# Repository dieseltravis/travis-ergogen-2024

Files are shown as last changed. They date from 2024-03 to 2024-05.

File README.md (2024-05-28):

# Travis's Ergogen Keyboard 2024 #
Built with Ergogen v4. *Beta* quality!

keyboard plate outline

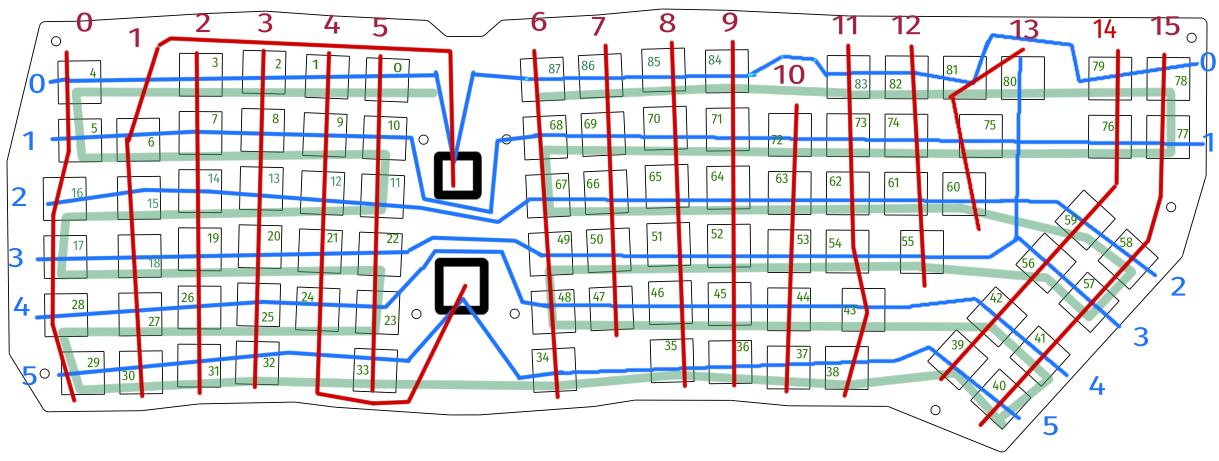
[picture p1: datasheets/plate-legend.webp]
rough keyboard key and led mapping


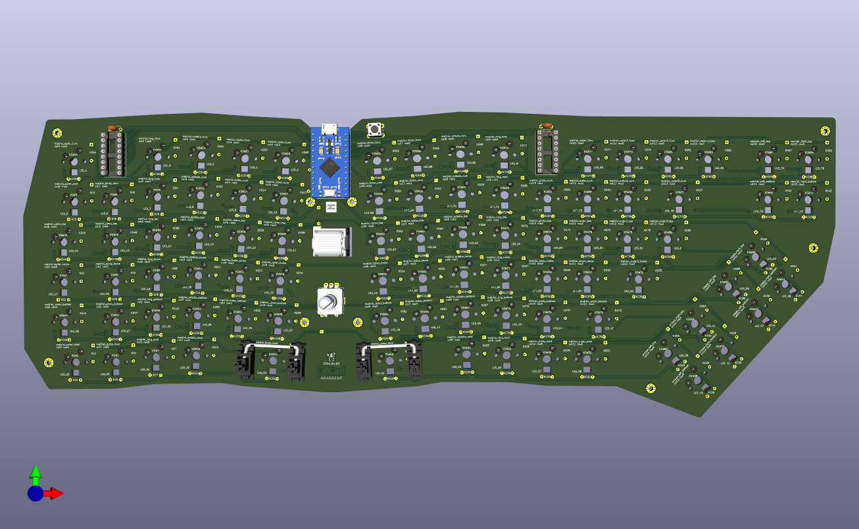
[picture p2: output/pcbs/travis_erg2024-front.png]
PCB front


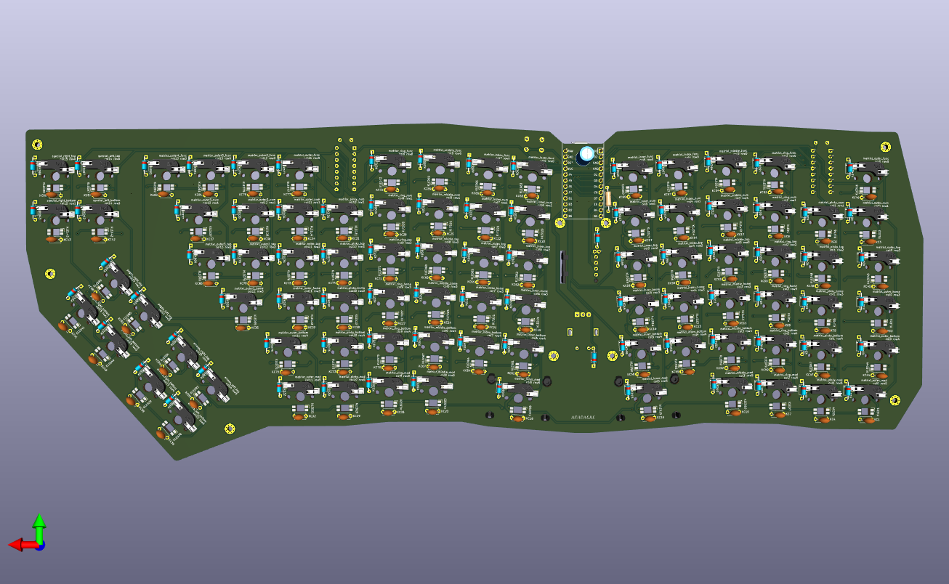
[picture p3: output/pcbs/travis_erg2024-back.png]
PCB back


keyboard-layout-editor.com

## Project Details ##
* `/config.yaml` Ergogen layout
* `/package.json` yarn commands and metadata
* `/output/outlines/` generated 2d models
* `/output/cases/` generated 3d models
* `/output/pcbs/` generated PCB
* `/footprints/travis/` Custom parts' footprints
    * `/footprints/travis/travis.pretty/` KiCad footprints
* `/key/` generator for individual key footprint (key-module.js)
    * `/keytest/` test for individual key footprint
* `/datasheets/` PDFs for some of the parts used
* `/kle/` keyboard-layout-editor.com layouts
* `/firmware/` qmk firmware compiles, but needs to be tested!

## References ##
* Ergogen project: https://github.com/ergogen/ergogen/
    * https://ergogen.cache.works/
    * https://ergogen.xyz/
* FlatFootFox's Let's Design A Keyboard With Ergogen v4 https://flatfootfox.com/ergogen-introduction/
* Footprints:
    * ceoloide's Ergogen PCB footprints https://github.com/ceoloide/ergogen-footprints
    * infused-kim's Ergogen PCB footprints https://github.com/infused-kim/kb_ergogen_fp/
    * TildeWill's Ergogen PCB footprints https://github.com/TildeWill/ergogen_footprints
    * MvEerd https://github.com/MvEerd/ergogen/tree/mveerd/src/footprints
    * daprice's keyswitches.pretty https://github.com/daprice/keyswitches.pretty
    * joe-scotto's scottokeebs: https://github.com/joe-scotto/scottokeebs/tree/main/Extras/ScottoKicad
    * Convert Kicad Footprints to Ergogen https://nilnil.notion.site/Convert-Kicad-Footprints-to-Ergogen-8340ce87ad554c69af4e3f92bc9a0898
    * KiCad Footprints: https://kicad.github.io/footprints/
* Other helpful build guides:
    * ceoloide's corney-island build https://github.com/ceoloide/corney-island
    * zzeneg's stront40 https://github.com/zzeneg/stront/tree/stront40
    * Minecatr's Splinar+ https://github.com/Minecatr/keyboards/
    * Kimiko Build Guide https://keycapsss.com/help/kimiko/buildguide_en
    * Nullbits Nibble https://github.com/nullbitsco/docs/blob/main/nibble/build_guide_en.md
    * Lagom https://github.com/mohoyt/lagom/
    * Sundown-keyboard https://github.com/Richiban/Sundown-keyboard/
    * Mantis hex ergo keyboard https://github.com/fxkuehl/mantis/
    * Sofle Keyboard https://github.com/josefadamcik/SofleKeyboard

## Parts ##

Aliexpress:
* Diodes: DO-35 1N4148 100pcs https://www.aliexpress.us/item/3256805608834808.html
* Rotary encoder: EC11 12.5mm 5pcs https://www.aliexpress.us/item/2251832789732148.html
* EVQWGD001 Encoder: https://www.aliexpress.us/item/3256806010310254.html
* IC SN74HC138N 10pcs https://www.aliexpress.us/item/3256806021872320.html
* RGB LEDs: SK6812 MINI-E 100pcs https://www.aliexpress.us/item/2255800289371100.html
* Capacitors: 104(0.1uF) 100pcs https://www.aliexpress.us/item/3256802104127109.html
* Resistor: 470R 100pcs https://www.aliexpress.us/item/3256801441680644.html
* Electrolytic Capacitor: 6.3V1000UF 6x11mm 10pcs https://www.aliexpress.us/item/3256802796040934.html

Adafruit:
* Adafruit KB2040 - RP2040 Kee Boar Driver https://www.adafruit.com/product/5302
* 5 @ Kailh Switch Sockets for MX-compatible Mechanical Keys - 20 Pack https://www.adafruit.com/product/4958
* 10 @ Kailh Mechanical Key Switches - Tactile Brown - 10 pack - Cherry MX Brown Compatible https://www.adafruit.com/product/4954
* 10 @ DSA Keycaps for MX Compatible Switches - 10 pack https://www.adafruit.com/product/5008
* USB A to USB C Cable - 2 meters long https://www.adafruit.com/product/5044

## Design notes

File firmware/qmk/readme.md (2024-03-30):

# dieseltravis/travis_ergogen_2024

dieseltravis/travis_ergogen_2024

*A short description of the keyboard/project*

* Keyboard Maintainer: [Travis Hardiman](https://github.com/dieseltravis)
* Hardware Supported: *The PCBs, controllers supported*
* Hardware Availability: *Links to where you can find this hardware*

Make example for this keyboard (after setting up your build environment):

    make dieseltravis/travis_ergogen_2024:default

Flashing example for this keyboard:

    make dieseltravis/travis_ergogen_2024:default:flash

See the [build environment setup](https://docs.qmk.fm/#/getting_started_build_tools) and the [make instructions](https://docs.qmk.fm/#/getting_started_make_guide) for more information. Brand new to QMK? Start with our [Complete Newbs Guide](https://docs.qmk.fm/#/newbs).

## Bootloader

Enter the bootloader in 3 ways:

* **Bootmagic reset**: Hold down the key at (0,0) in the matrix (usually the top left key or Escape) and plug in the keyboard
* **Physical reset button**: Briefly press the button on the back of the PCB - some may have pads you must short instead
* **Keycode in layout**: Press the key mapped to `RESET` if it is available

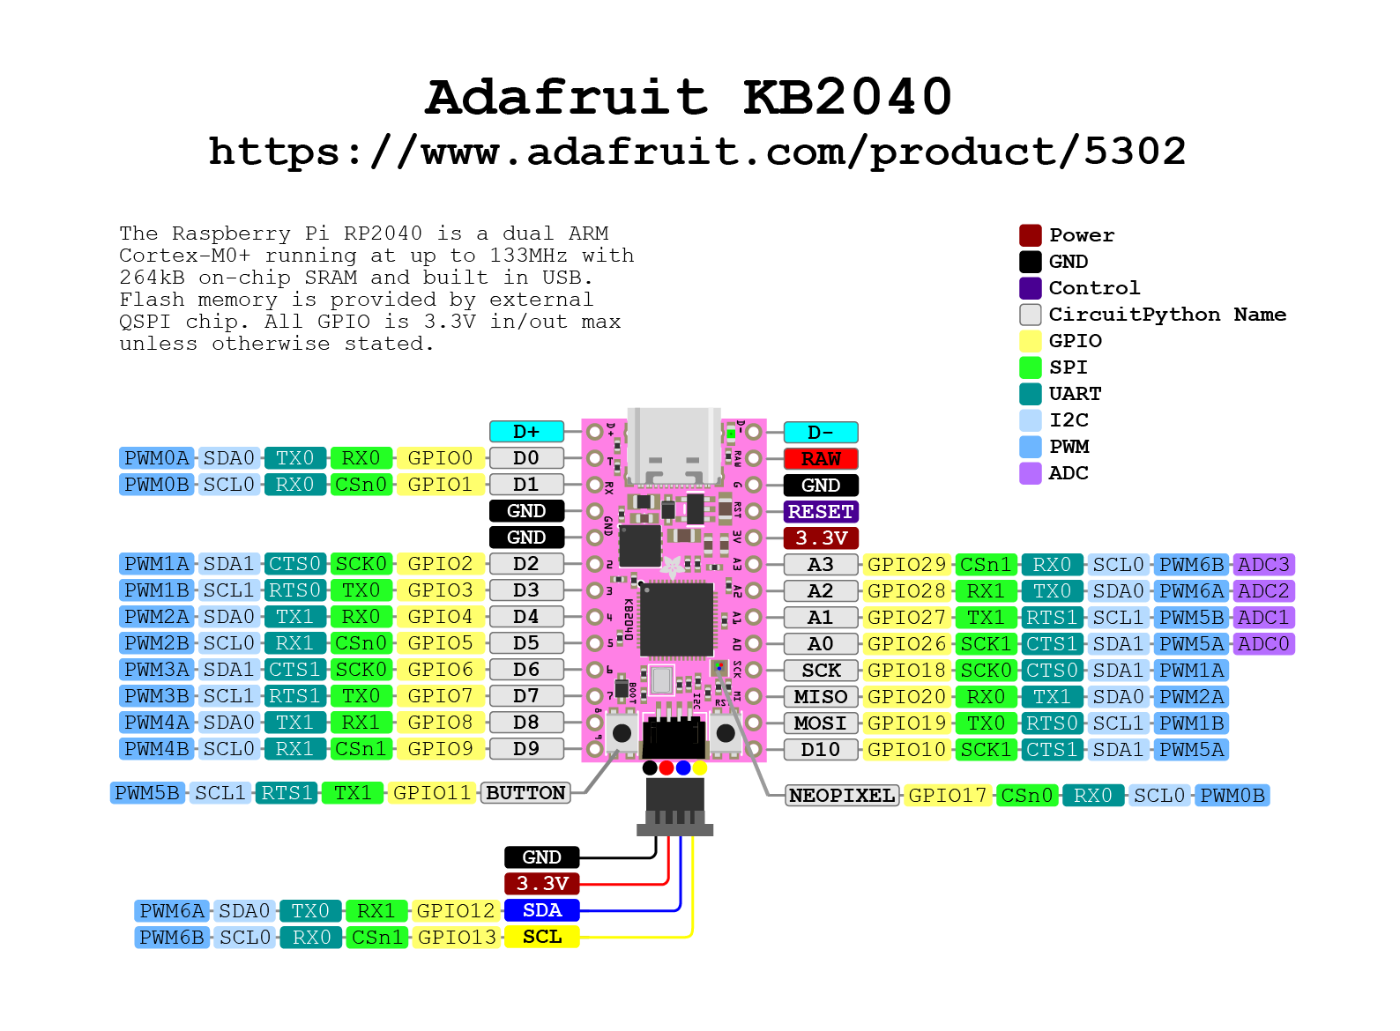
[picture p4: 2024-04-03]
datasheets/adafruit_products_Adafruit_KB2040_Pinout.png

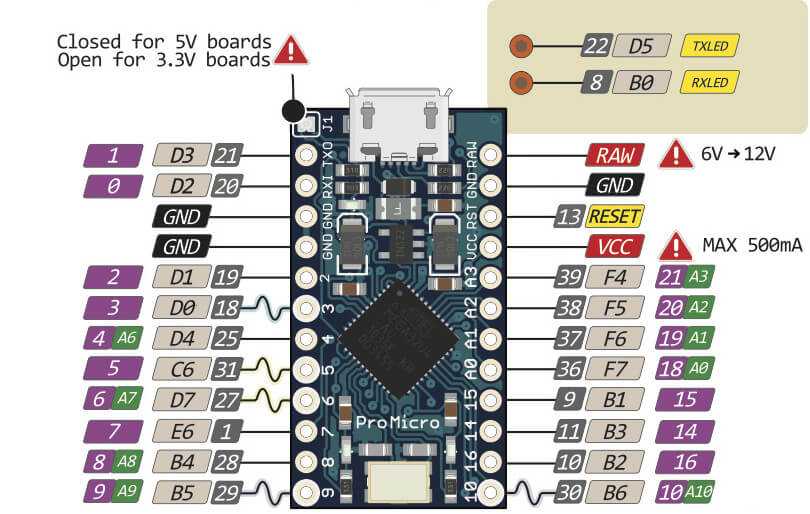
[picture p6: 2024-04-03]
datasheets/pro_micro_pinout.jpeg

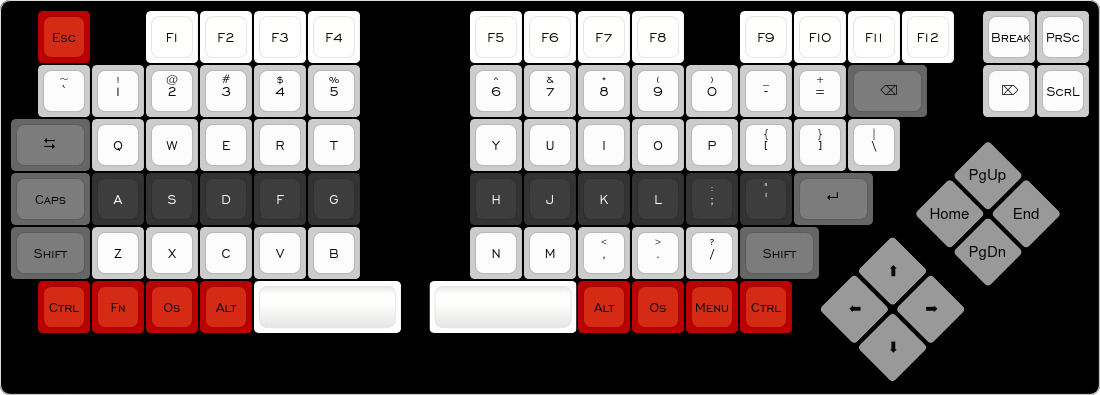
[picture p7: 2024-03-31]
kle/travis-ergogen-2024.jpg

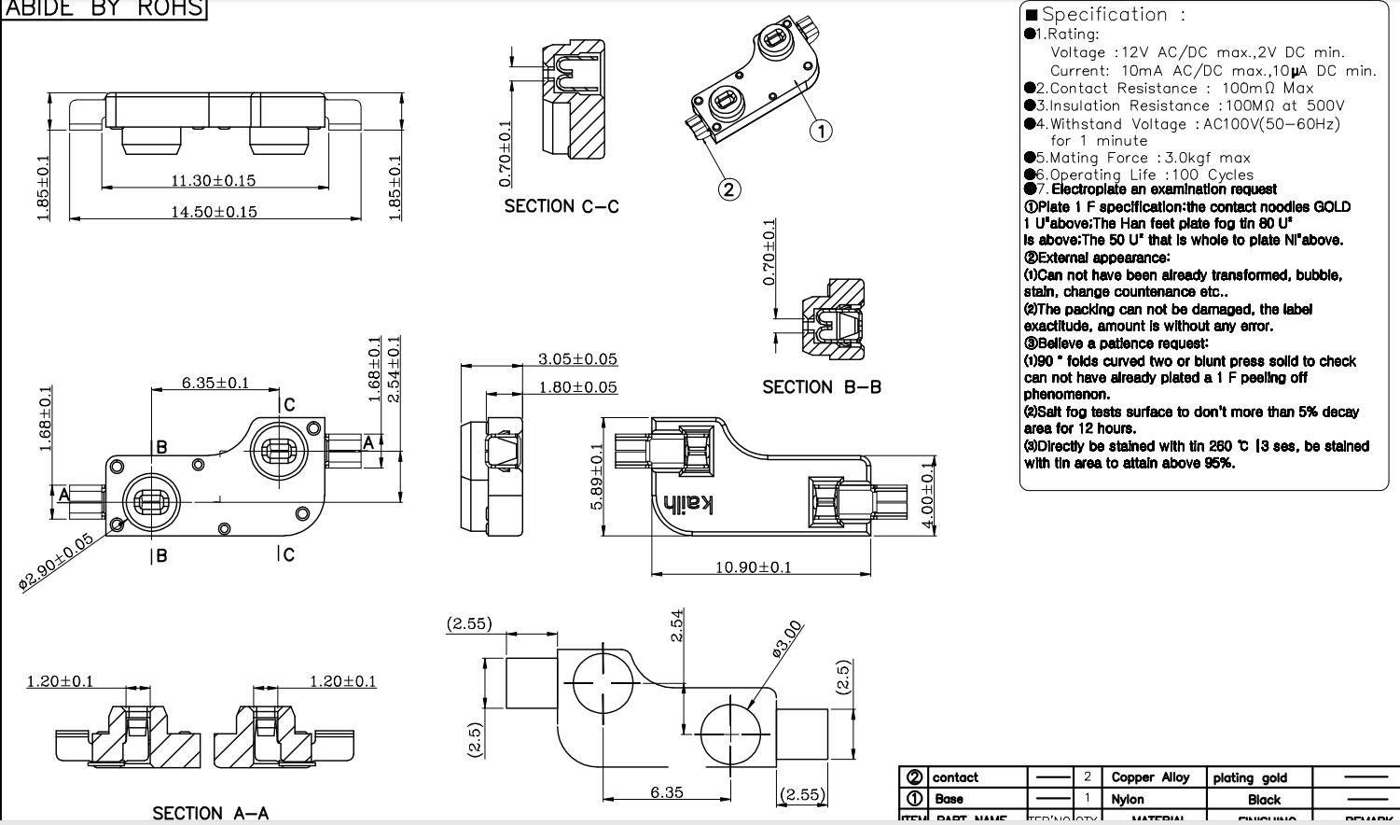
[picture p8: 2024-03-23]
datasheets/Kailh Switch Sockets Datasheet.jpeg

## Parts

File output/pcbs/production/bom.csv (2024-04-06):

Designator | Footprint | Quantity | Value | LCSC Part #
C1 | C_Radial_D6.3mm_H11.0mm_P2.50mm | 1 | 6.3V 1000uF
C2, C3, KC1, KC10, KC11, KC12, KC13, KC14, KC15, KC16, KC17, KC18, KC19, KC2, KC20, KC21, KC22, KC23, KC24, KC25, KC26, KC27, KC28, KC29, KC3, KC30, KC31, KC32, KC33, KC34, KC35, KC36, KC37, KC38, KC39, KC4, KC40, KC41, KC42, KC43, KC44, KC45, KC46, KC47, KC48, KC49, KC5, KC50, KC51, KC52, KC53, KC54, KC55, KC56, KC57, KC58, KC59, KC6, KC60, KC61, KC62, KC63, KC64, KC65, KC66, KC67, KC68, KC69, KC7, KC70, KC71, KC72, KC73, KC74, KC75, KC76, KC77, KC78, KC79, KC8, KC80, KC81, KC82, KC83, KC84, KC85, KC86, KC87, KC88, KC9 | C_Disc_D4.7mm_W2.5mm_P5.00mm | 90 | 104
D1, D2, KD1, KD10, KD11, KD12, KD13, KD14, KD15, KD16, KD17, KD18, KD19, KD2, KD20, KD21, KD22, KD23, KD24, KD25, KD26, KD27, KD28, KD29, KD3, KD30, KD31, KD32, KD33, KD34, KD35, KD36, KD37, KD38, KD39, KD4, KD40, KD41, KD42, KD43, KD44, KD45, KD46, KD47, KD48, KD49, KD5, KD50, KD51, KD52, KD53, KD54, KD55, KD56, KD57, KD58, KD59, KD6, KD60, KD61, KD62, KD63, KD64, KD65, KD66, KD67, KD68, KD69, KD7, KD70, KD71, KD72, KD73, KD74, KD75, KD76, KD77, KD78, KD79, KD8, KD80, KD81, KD82, KD83, KD84, KD85, KD86, KD87, KD88, KD9 | Diode_DO-35 | 90 | 1N4148
DIP1, DIP2 | DIP-16_W7.62mm_Socket | 2 | SN74HC138N
HOLE1, HOLE2, HOLE3, HOLE4, HOLE5, HOLE6, HOLE7, HOLE8, HOLE9 | MountingHole_2.2mm_M2_Pad_Via | 9
KLED1, KLED10, KLED11, KLED12, KLED13, KLED14, KLED15, KLED16, KLED17, KLED18, KLED19, KLED2, KLED20, KLED21, KLED22, KLED23, KLED24, KLED25, KLED26, KLED27, KLED28, KLED29, KLED3, KLED30, KLED31, KLED32, KLED33, KLED34, KLED35, KLED36, KLED37, KLED38, KLED39, KLED4, KLED40, KLED41, KLED42, KLED43, KLED44, KLED45, KLED46, KLED47, KLED48, KLED49, KLED5, KLED50, KLED51, KLED52, KLED53, KLED54, KLED55, KLED56, KLED57, KLED58, KLED59, KLED6, KLED60, KLED61, KLED62, KLED63, KLED64, KLED65, KLED66, KLED67, KLED68, KLED69, KLED7, KLED70, KLED71, KLED72, KLED73, KLED74, KLED75, KLED76, KLED77, KLED78, KLED79, KLED8, KLED80, KLED81, KLED82, KLED83, KLED84, KLED85, KLED86, KLED87, KLED88, KLED9 | led_SK6812mini-e | 88 | SK6812mini-e
KSW1, KSW10, KSW11, KSW12, KSW13, KSW14, KSW15, KSW16, KSW17, KSW18, KSW19, KSW2, KSW20, KSW21, KSW22, KSW23, KSW24, KSW25, KSW26, KSW27, KSW28, KSW29, KSW3, KSW30, KSW31, KSW32, KSW33, KSW34, KSW35, KSW36, KSW37, KSW38, KSW39, KSW4, KSW40, KSW41, KSW42, KSW43, KSW44, KSW45, KSW46, KSW47, KSW48, KSW49, KSW5, KSW50, KSW51, KSW52, KSW53, KSW54, KSW55, KSW56, KSW57, KSW58, KSW59, KSW6, KSW60, KSW61, KSW62, KSW63, KSW64, KSW65, KSW66, KSW67, KSW68, KSW69, KSW7, KSW70, KSW71, KSW72, KSW73, KSW74, KSW75, KSW76, KSW77, KSW78, KSW79, KSW8, KSW80, KSW81, KSW82, KSW83, KSW84, KSW85, KSW86, KSW87, KSW88, KSW9 | MX | 88 | Kailh MX Switch Sockets
MCU1 | Arduino_Pro_Micro | 1 | Arduino Pro Micro
R1 | R_Axial_DIN0207_L6.3mm_D2.5mm_P10.16mm_Horizontal | 1 | 470R
ROT1 | ec11 | 1 | EC11
SCR1 | evqwgd001 | 1 | EVQWGD001
SW1 | SW_PUSH_6mm_H4.3mm | 1 | 6mm button

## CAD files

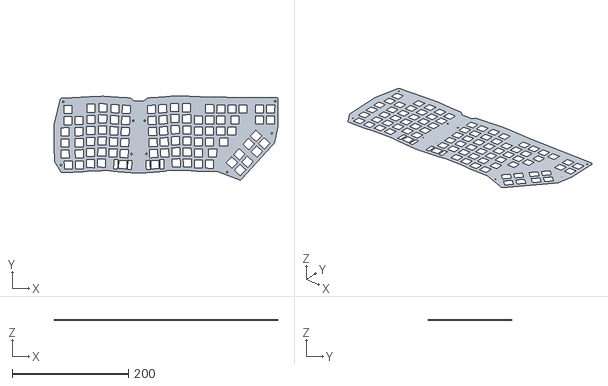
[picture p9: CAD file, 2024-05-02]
output/cases/plate3d.stl
385.3 x 144.8 x 1.00

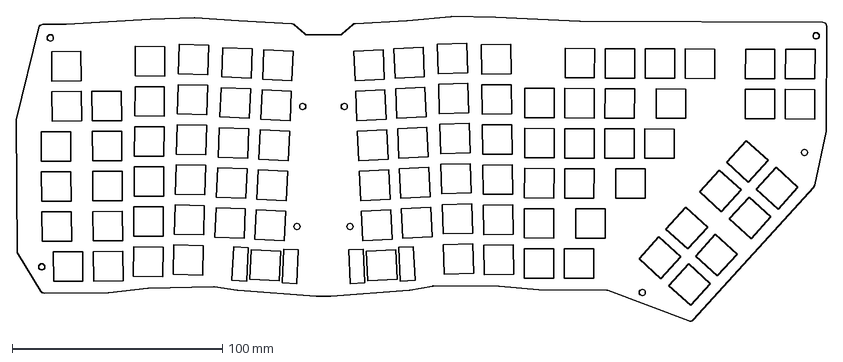
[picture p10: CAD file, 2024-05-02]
output/outlines/plate.dxf
385.3 x 145.0 mm

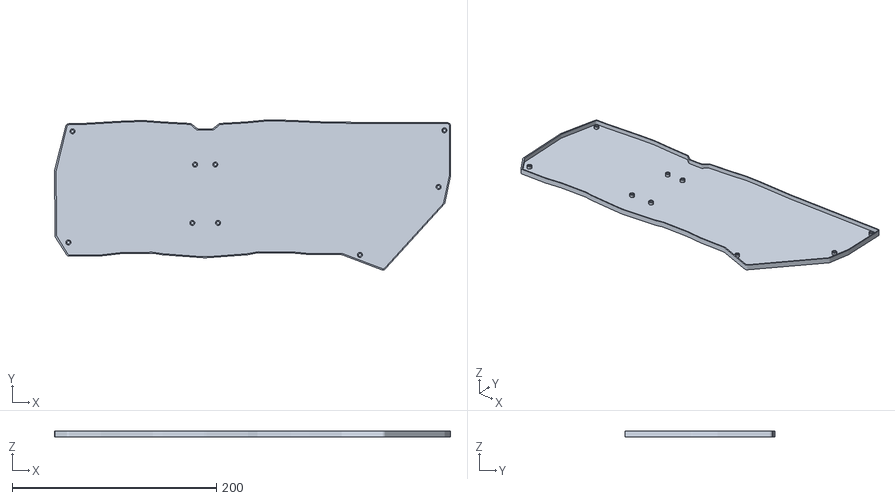
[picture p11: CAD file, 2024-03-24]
output/cases/case.stl
387.8 x 147.0 x 5.60

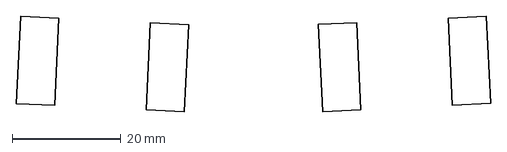
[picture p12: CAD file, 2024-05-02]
output/outlines/2u_stabilizer.dxf
87.0 x 17.5 mm

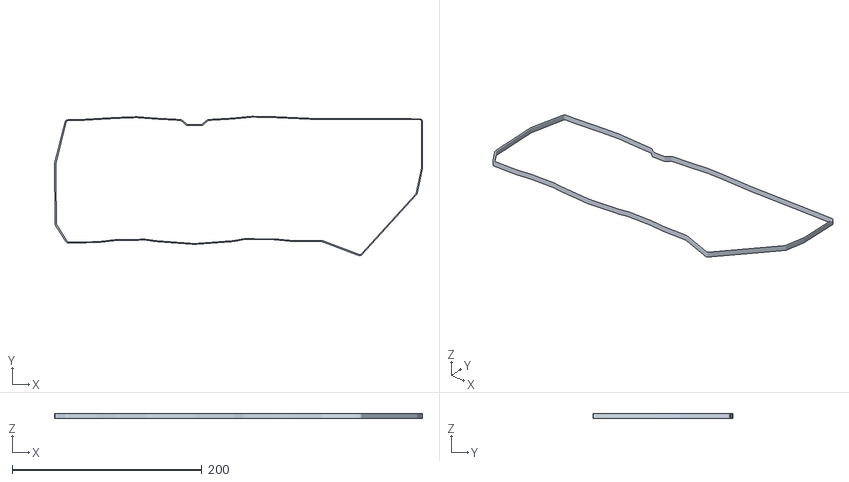
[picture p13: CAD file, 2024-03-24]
output/cases/wall.stl
387.8 x 147.0 x 5.60

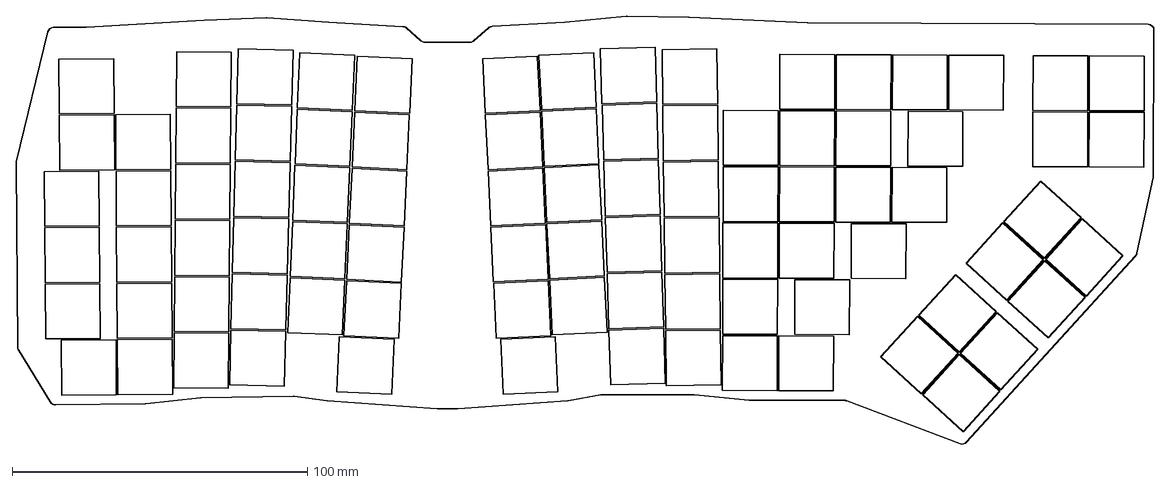
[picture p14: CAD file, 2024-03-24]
output/outlines/combo.dxf
385.3 x 145.0 mm

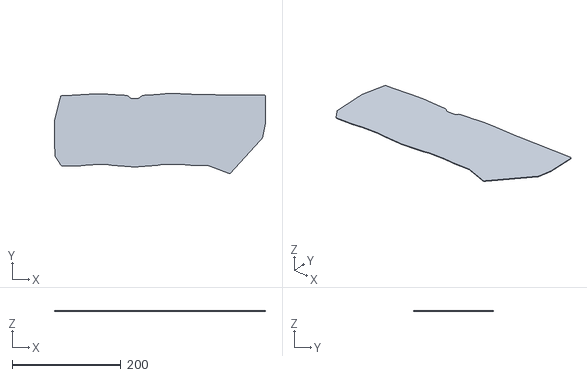
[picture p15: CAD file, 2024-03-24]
output/cases/bottom.stl
387.8 x 147.0 x 1.00

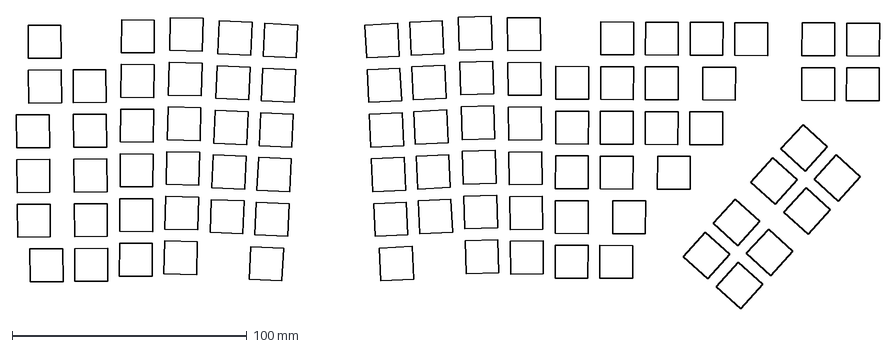
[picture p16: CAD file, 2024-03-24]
output/outlines/keyholes.dxf
367.9 x 124.6 mm

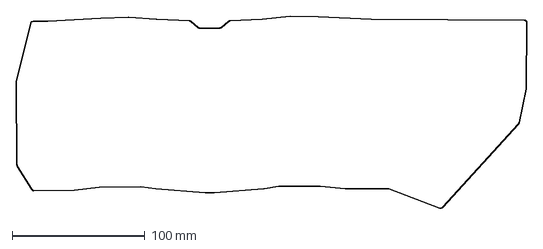
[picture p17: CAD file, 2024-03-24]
output/outlines/board.dxf
385.3 x 145.0 mm

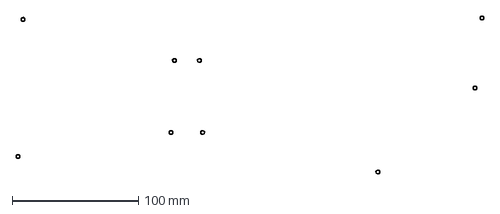
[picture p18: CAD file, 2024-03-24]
output/outlines/mounting.dxf
371.1 x 125.0 mm

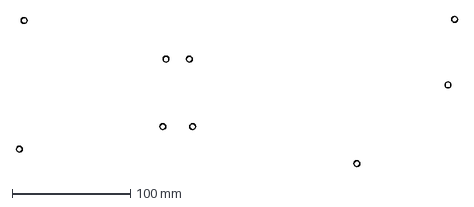
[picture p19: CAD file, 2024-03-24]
output/outlines/standoff.dxf
373.1 x 127.0 mm

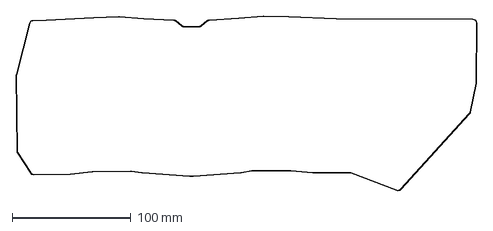
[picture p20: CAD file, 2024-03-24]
output/outlines/board3d.dxf
387.8 x 147.3 mm

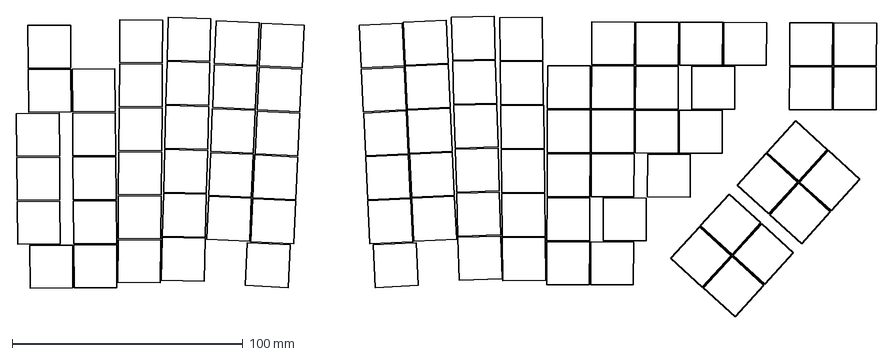
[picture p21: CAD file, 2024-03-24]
output/outlines/keys.dxf
372.4 x 130.1 mm

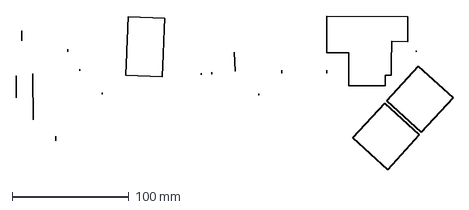
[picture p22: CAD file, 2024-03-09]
output/outlines/raw.dxf
373.6 x 130.9 mm

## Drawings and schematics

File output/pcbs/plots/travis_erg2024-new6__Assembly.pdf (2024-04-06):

1 | 2 | 3 | 4 | 5 | 6 | 7 | 8

A

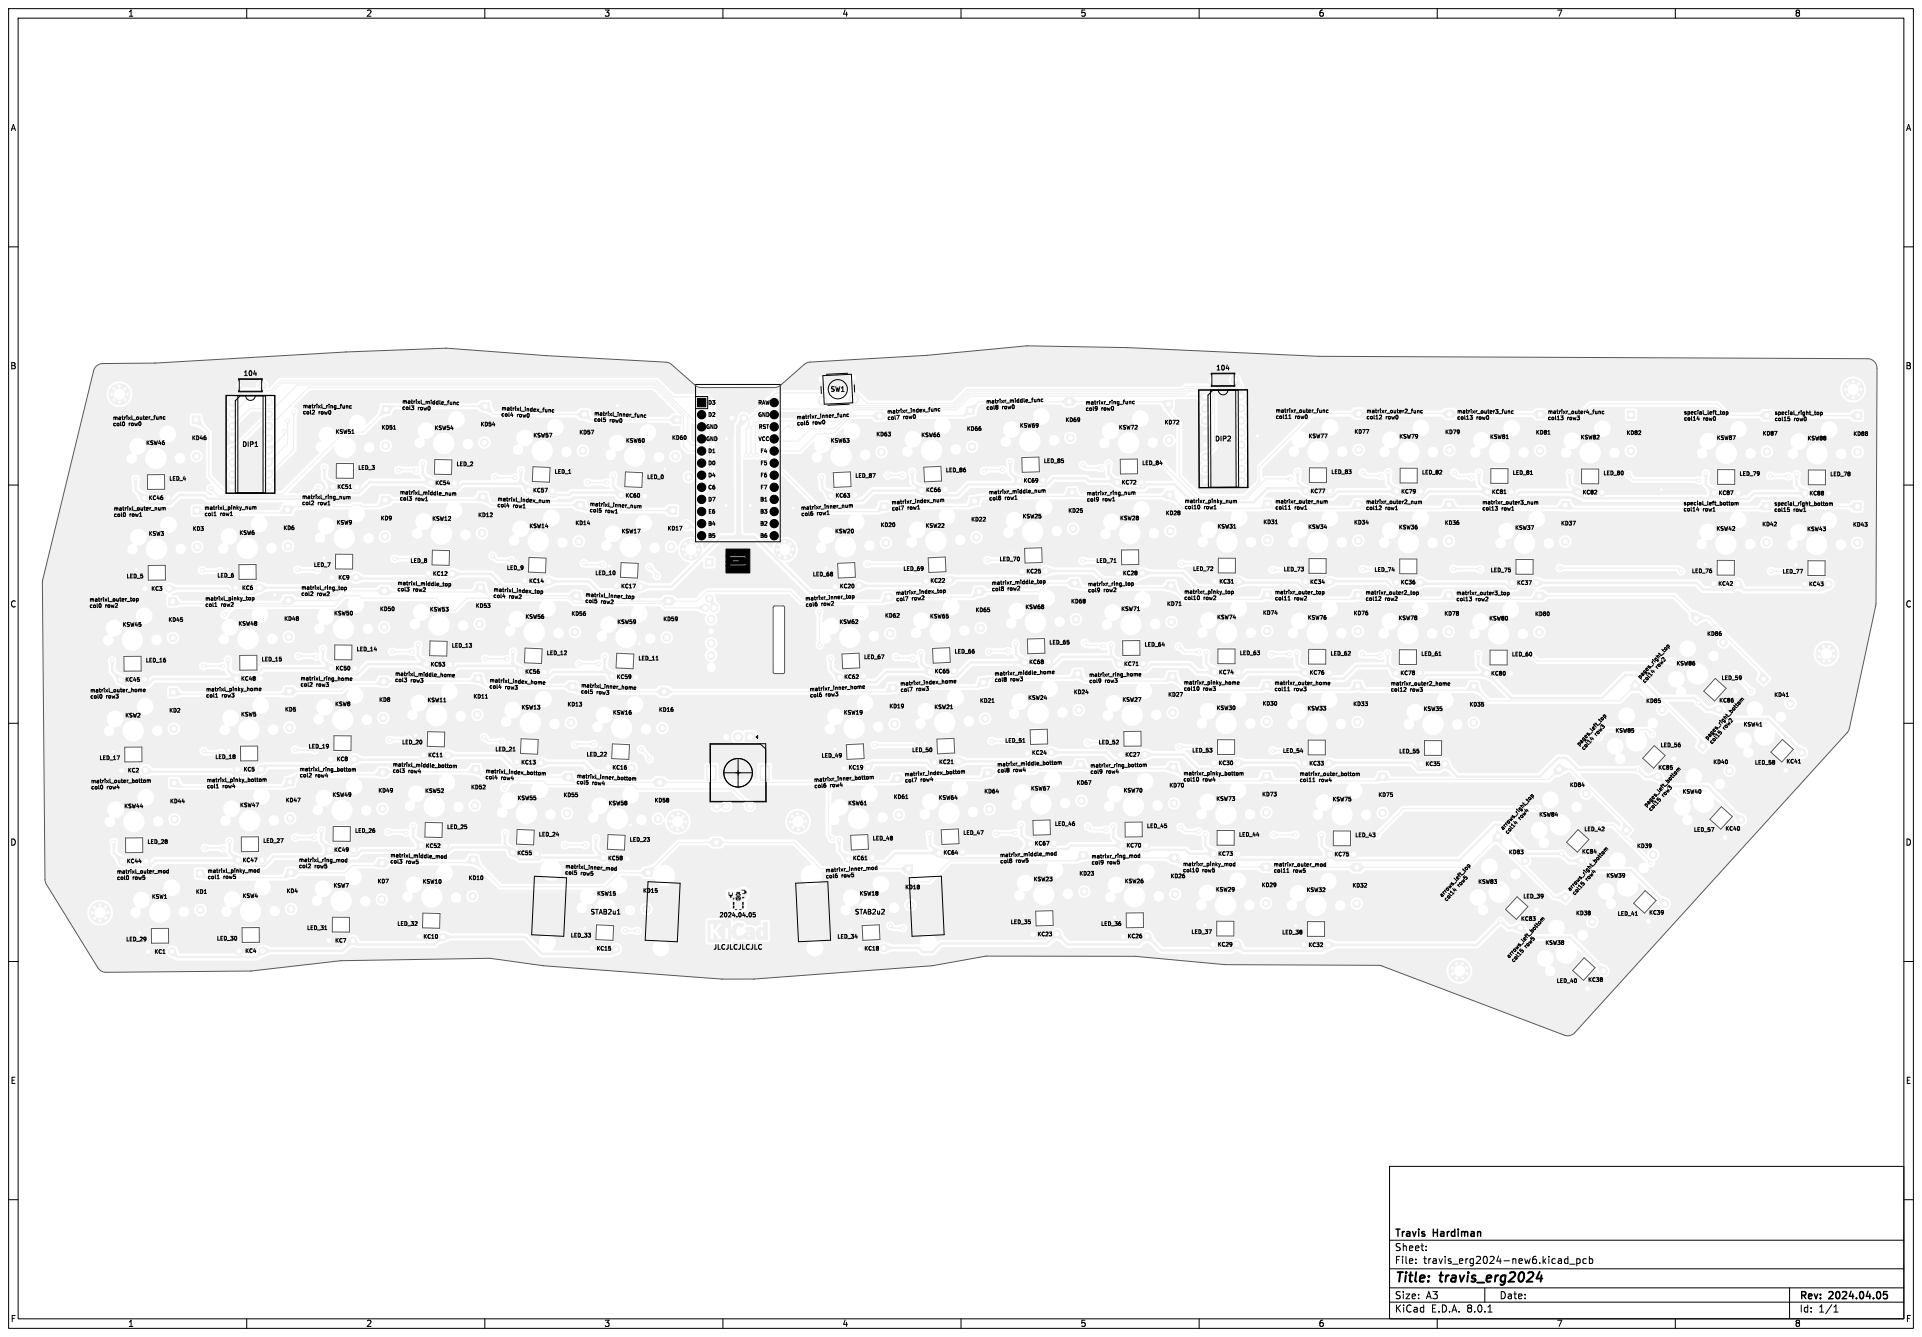
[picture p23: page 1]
matrixl_ring_func col2 row0 matrixr_index_bottom; col7 row4 KD24 KC47 matrixr_inner_home col6 row3 KD7; LED_23; LED_70 KC11; KC51 matrixl_outer_home; col0 row3 KD18 KC85; LED_3; matrixr_inner_num; col6 row1 matrixr_inner_func col6 row0 matrixr_outer_num; col11; row1 matrixr_middle_mod; col8 row5; KD59 matrixl_index_home; col4 row3 matrixl_outer_top col0 row2; LED_58 KD20 matrixl_index_num col4 row1 KC58; LED_78; matrixr_inner_top col6 row2 KC1; matrixr_ring_func col9 row0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

File: travis_erg2024-new6.kicad_pcb Sheet: Travis Hardiman

1 | 2 | 3 | 4 | 5 | 6 | 7 | 8

A

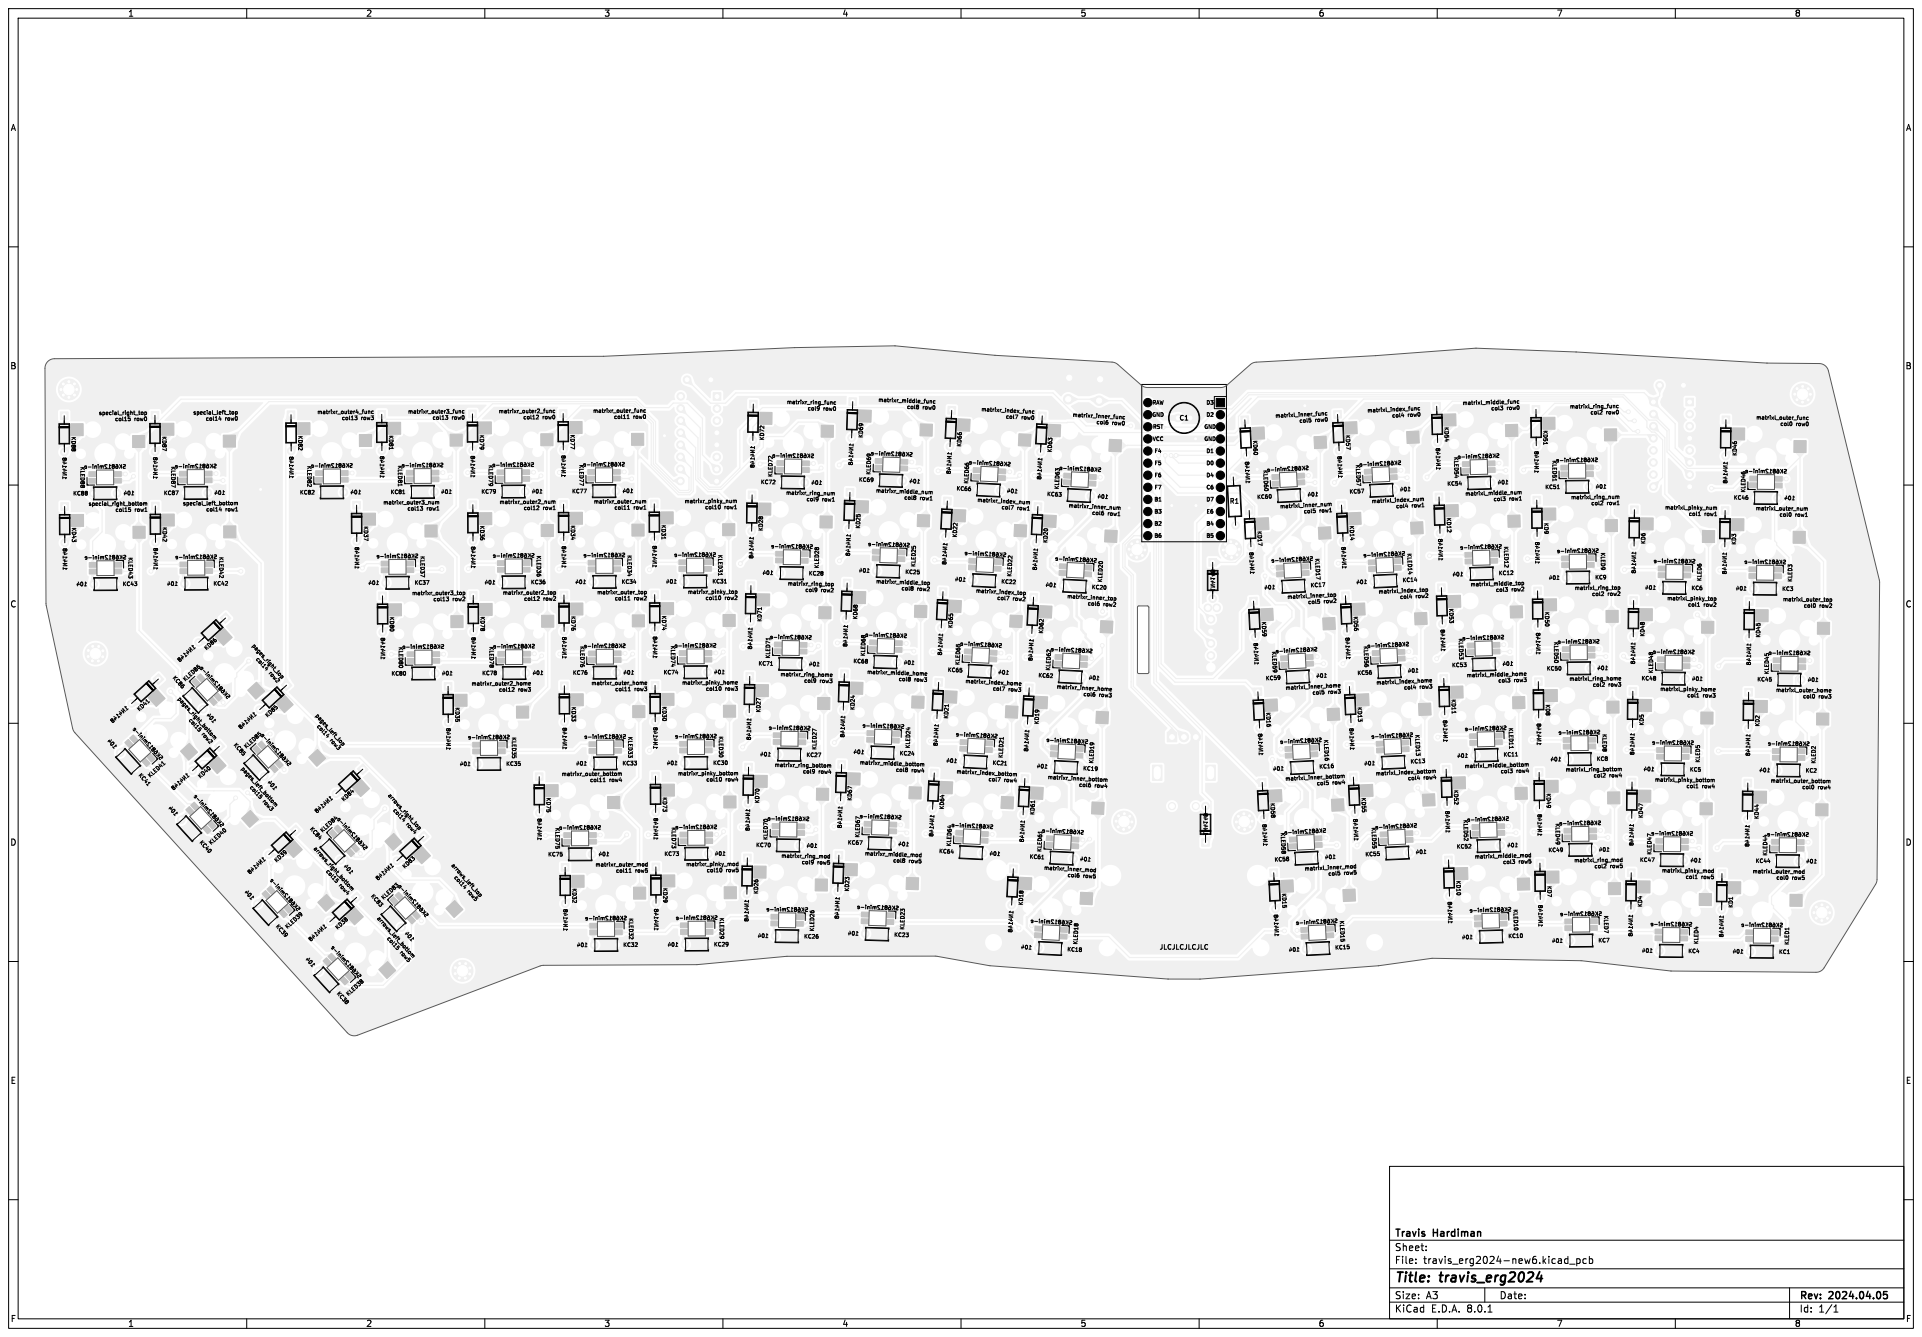
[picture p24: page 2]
matrixr_ring_home; col9 row3 matrixl_ring_func; col2 row0 matrixr_ring_func col9 row0 matrixr_inner_home; col6 row3 matrixr_inner_num; col6 row1 matrixr_outer2_num; col12; row1; matrixl_index_func; col4 row0 matrixr_inner_mod; col6 row5; arrows_left_bottom col15; row5; matrixl_pinky_bottom col1 row4; pages_right_bottom col15; row2; matrixl_pinky_mod col1 row5; matrixr_outer4_func; col13; row3; matrixr_middle_bottom; col8 row4; special_right_top; col15; row0; matrixl_pinky_num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

File: travis_erg2024-new6.kicad_pcb Sheet: Travis Hardiman

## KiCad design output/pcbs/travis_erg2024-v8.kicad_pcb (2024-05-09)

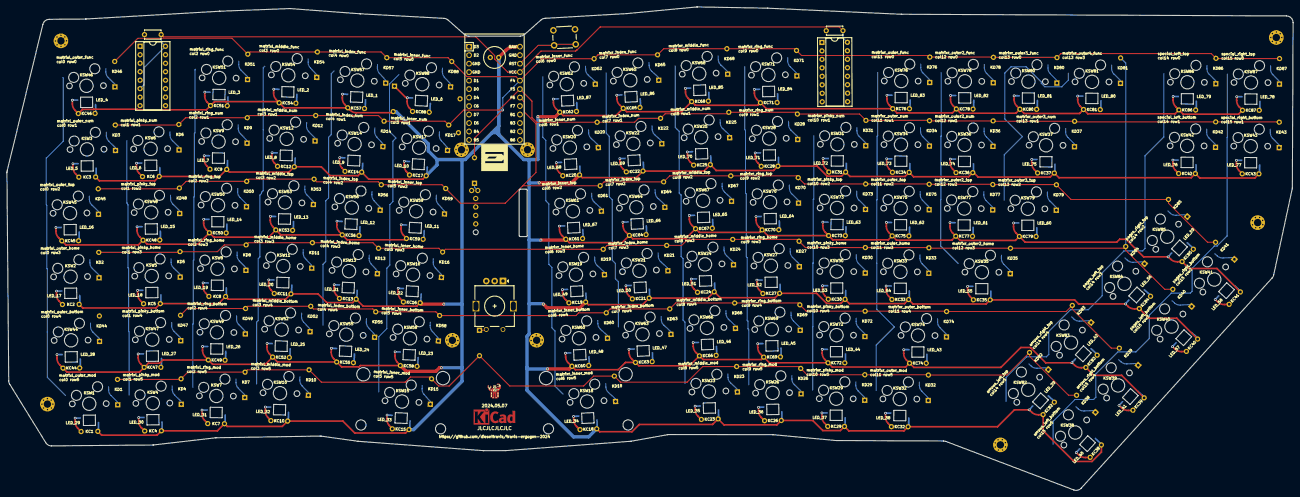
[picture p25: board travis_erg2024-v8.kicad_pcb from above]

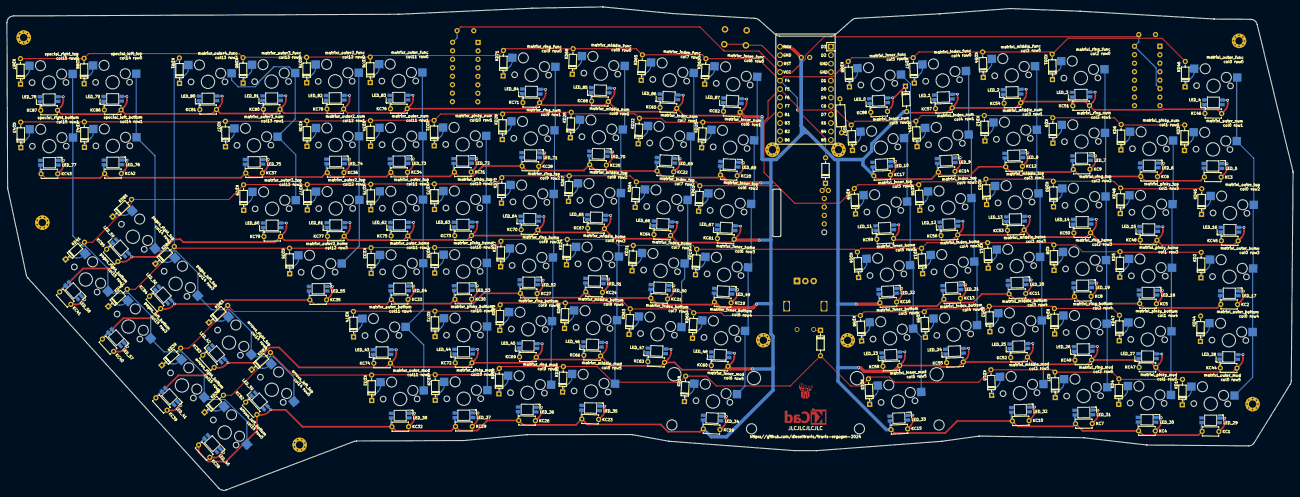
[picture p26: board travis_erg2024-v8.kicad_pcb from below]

Board: 2 copper layers, 385.3 x 144.8 mm, 379 parts (268 on the bottom side), 214 nets.

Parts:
C1: 6.3V 1000uF; C_Radial_D6.3mm_H11.0mm_P2.50mm
C2, C3: 104; C_Disc_D4.7mm_W2.5mm_P5.00mm
D1, D2, D3: 1N4148; Diode_DO-35
DIP1, DIP2: SN74HC138N; DIP-16_W7.62mm_Socket
HOLE1, HOLE2, HOLE3, HOLE4, HOLE5, HOLE6, HOLE7, HOLE8, HOLE9: MountingHole_2.2mm_M2_Pad_Via
KC1, KC2, KC3, KC4, KC5, KC6, KC7, KC8, KC9, KC10, KC11, KC12, KC13, KC14, KC15, KC16, KC17, KC18, KC19, KC20, KC21, KC22, KC23, KC24, KC25, KC26, KC27, KC28, KC29, KC30, KC31, KC32, KC33, KC34, KC35, KC36, KC37, KC38, KC39, KC40, KC41, KC42, KC43, KC44, KC45, KC46, KC47, KC48, KC49, KC50, KC51, KC52, KC53, KC54, KC55, KC56, KC57, KC58, KC59, KC60, KC61, KC62, KC63, KC64, KC65, KC66, KC67, KC68, KC69, KC70, KC71, KC72, KC73, KC74, KC75, KC76, KC77, KC78, KC79, KC80, KC81, KC82, KC83, KC84, KC85, KC86, KC87, KC88: 104; C_Disc_D4.7mm_W2.5mm_P5.00mm
KD1, KD2, KD3, KD4, KD5, KD6, KD7, KD8, KD9, KD10, KD11, KD12, KD13, KD14, KD15, KD16, KD17, KD18, KD19, KD20, KD21, KD22, KD23, KD24, KD25, KD26, KD27, KD28, KD29, KD30, KD31, KD32, KD33, KD34, KD35, KD36, KD37, KD38, KD39, KD40, KD41, KD42, KD43, KD44, KD45, KD46, KD47, KD48, KD49, KD50, KD51, KD52, KD53, KD54, KD55, KD56, KD57, KD58, KD59, KD60, KD61, KD62, KD63, KD64, KD65, KD66, KD67, KD68, KD69, KD70, KD71, KD72, KD73, KD74, KD75, KD76, KD77, KD78, KD79, KD80, KD81, KD82, KD83, KD84, KD85, KD86, KD87, KD88: 1N4148; Diode_DO-35
KSW1, KSW2, KSW3, KSW4, KSW5, KSW6, KSW7, KSW8, KSW9, KSW10, KSW11, KSW12, KSW13, KSW14, KSW15, KSW16, KSW17, KSW18, KSW19, KSW20, KSW21, KSW22, KSW23, KSW24, KSW25, KSW26, KSW27, KSW28, KSW29, KSW30, KSW31, KSW32, KSW33, KSW34, KSW35, KSW36, KSW37, KSW38, KSW39, KSW40, KSW41, KSW42, KSW43, KSW44, KSW45, KSW46, KSW47, KSW48, KSW49, KSW50, KSW51, KSW52, KSW53, KSW54, KSW55, KSW56, KSW57, KSW58, KSW59, KSW60, KSW61, KSW62, KSW63, KSW64, KSW65, KSW66, KSW67, KSW68, KSW69, KSW70, KSW71, KSW72, KSW73, KSW74, KSW75, KSW76, KSW77, KSW78, KSW79, KSW80, KSW81, KSW82, KSW83, KSW84, KSW85, KSW86, KSW87, KSW88: Kailh MX Switch Sockets; MX
LED_0-row0-col5, LED_1-row0-col4, LED_2-row0-col3, LED_3-row0-col2, LED_4-row0-col0, LED_5-row1-col0, LED_6-row1-col1, LED_7-row1-col2, LED_8-row1-col3, LED_9-row1-col4, LED_10-row1-col5, LED_11-row2-col5, LED_12-row2-col4, LED_13-row2-col3, LED_14-row2-col2, LED_15-row2-col1, LED_16-row2-col0, LED_17-row3-col0, LED_18-row3-col1, LED_19-row3-col2, LED_20-row3-col3, LED_21-row3-col4, LED_22-row3-col5, LED_23-row4-col5, LED_24-row4-col4, LED_25-row4-col3, LED_26-row4-col2, LED_27-row4-col1, LED_28-row4-col0, LED_29-row5-col0, LED_30-row5-col1, LED_31-row5-col2, LED_32-row5-col3, LED_33-row5-col5, LED_34-row5-col6, LED_35-row5-col8, LED_36-row5-col9, LED_37-row5-col10, LED_38-row5-col11, LED_39-row5-col14, LED_40-row5-col15, LED_41-row4-col15, LED_42-row4-col14, LED_43-row4-col11, LED_44-row4-col10, LED_45-row4-col9, LED_46-row4-col8, LED_47-row4-col7, LED_48-row4-col6, LED_49-row3-col6, LED_50-row3-col7, LED_51-row3-col8, LED_52-row3-col9, LED_53-row3-col10, LED_54-row3-col11, LED_55-row3-col12, LED_56-row3-col14, LED_57-row3-col15, LED_58-row2-col15, LED_59-row2-col14, LED_60-row2-col13, LED_61-row2-col12, LED_62-row2-col11, LED_63-row2-col10, LED_64-row2-col9, LED_65-row2-col8, LED_66-row2-col7, LED_67-row2-col6, LED_68-row1-col6, LED_69-row1-col7, LED_70-row1-col8, LED_71-row1-col9, LED_72-row1-col10, LED_73-row1-col11, LED_74-row1-col12, LED_75-row1-col13, LED_76-row1-col14, LED_77-row1-col15, LED_78-row0-col15, LED_79-row0-col14, LED_80-row3-col13, LED_81-row0-col13, LED_82-row0-col12, LED_83-row0-col11, LED_84-row0-col9, LED_85-row0-col8, LED_86-row0-col7, LED_87-row0-col6: SK6812mini-e; led_SK6812mini-e
LOGO1: ergogen_logo
LOGO2: travis
MCU1: Arduino Pro Micro; Arduino_Pro_Micro
R1: 470R; R_Axial_DIN0207_L6.3mm_D2.5mm_P10.16mm_Horizontal
ROT1: EC11; ec11
SCR1: EVQWGD001; evqwgd001
STAB2u1, STAB2u2: Stabilizer_MX_2.00u
SW1: 6mm button; SW_PUSH_6mm_H4.3mm
SYM1: KiCad-Logo_5mm_Copper

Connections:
GND: C1.2, C2.2, C3.2, DIP1.4, DIP1.8, DIP2.4, DIP2.5, DIP2.8, KC1.2, KC2.2, KC3.2, KC4.2, KC5.2, KC6.2, KC7.2, KC8.2, KC9.2, KC10.2, KC11.2, KC12.2, KC13.2, KC14.2, KC15.2, KC16.2, KC17.2, KC18.2, KC19.2, KC20.2, KC21.2, KC22.2, KC23.2, KC24.2, KC25.2, KC26.2, KC27.2, KC28.2, KC29.2, KC30.2, KC31.2, KC32.2, KC33.2, KC34.2, KC35.2, KC36.2, KC37.2, KC38.2, KC39.2, KC40.2, KC41.2, KC42.2, KC43.2, KC44.2, KC45.2, KC46.2, KC47.2, KC48.2, KC49.2, KC50.2, KC51.2, KC52.2, KC53.2, KC54.2, KC55.2, KC56.2, KC57.2, KC58.2, KC59.2, KC60.2, KC61.2, KC62.2, KC63.2, KC64.2, KC65.2, KC66.2, KC67.2, KC68.2, KC69.2, KC70.2, KC71.2, KC72.2, KC73.2, KC74.2, KC75.2, KC76.2, KC77.2, KC78.2, KC79.2, KC80.2, KC81.2, KC82.2, KC83.2, KC84.2, KC85.2, KC86.2, KC87.2, KC88.2, LED_0-row0-col5.3, LED_1-row0-col4.3, LED_2-row0-col3.3, LED_3-row0-col2.3, LED_4-row0-col0.3, LED_5-row1-col0.3, LED_6-row1-col1.3, LED_7-row1-col2.3, LED_8-row1-col3.3, LED_9-row1-col4.3, LED_10-row1-col5.3, LED_11-row2-col5.3, LED_12-row2-col4.3, LED_13-row2-col3.3, LED_14-row2-col2.3, LED_15-row2-col1.3, LED_16-row2-col0.3, LED_17-row3-col0.3, LED_18-row3-col1.3, LED_19-row3-col2.3, LED_20-row3-col3.3, LED_21-row3-col4.3, LED_22-row3-col5.3, LED_23-row4-col5.3, LED_24-row4-col4.3, LED_25-row4-col3.3, LED_26-row4-col2.3, LED_27-row4-col1.3, LED_28-row4-col0.3, LED_29-row5-col0.3, LED_30-row5-col1.3, LED_31-row5-col2.3, LED_32-row5-col3.3, LED_33-row5-col5.3, LED_34-row5-col6.3, LED_35-row5-col8.3, LED_36-row5-col9.3, LED_37-row5-col10.3, LED_38-row5-col11.3, LED_39-row5-col14.3, LED_40-row5-col15.3, LED_41-row4-col15.3, LED_42-row4-col14.3, LED_43-row4-col11.3, LED_44-row4-col10.3, LED_45-row4-col9.3, LED_46-row4-col8.3, LED_47-row4-col7.3, LED_48-row4-col6.3, LED_49-row3-col6.3, LED_50-row3-col7.3, LED_51-row3-col8.3, LED_52-row3-col9.3, LED_53-row3-col10.3, LED_54-row3-col11.3, LED_55-row3-col12.3, LED_56-row3-col14.3, LED_57-row3-col15.3, LED_58-row2-col15.3, LED_59-row2-col14.3, LED_60-row2-col13.3, LED_61-row2-col12.3, LED_62-row2-col11.3, LED_63-row2-col10.3, LED_64-row2-col9.3, LED_65-row2-col8.3, LED_66-row2-col7.3, LED_67-row2-col6.3, LED_68-row1-col6.3, LED_69-row1-col7.3, LED_70-row1-col8.3, LED_71-row1-col9.3, LED_72-row1-col10.3, LED_73-row1-col11.3, LED_74-row1-col12.3, LED_75-row1-col13.3, LED_76-row1-col14.3, LED_77-row1-col15.3, LED_78-row0-col15.3, LED_79-row0-col14.3, LED_80-row3-col13.3, LED_81-row0-col13.3, LED_82-row0-col12.3, LED_83-row0-col11.3, LED_84-row0-col9.3, LED_85-row0-col8.3, LED_86-row0-col7.3, LED_87-row0-col6.3, MCU1.3, MCU1.4, MCU1.23, ROT1.B, SCR1.B, SW1.1
LED: MCU1.12, R1.1
LED_0: LED_0-row0-col5.4, R1.2
LED_1: LED_0-row0-col5.2, LED_1-row0-col4.4
LED_2: LED_1-row0-col4.2, LED_2-row0-col3.4
LED_3: LED_2-row0-col3.2, LED_3-row0-col2.4
LED_4: LED_3-row0-col2.2, LED_4-row0-col0.4
LED_5: LED_4-row0-col0.2, LED_5-row1-col0.4
LED_6: LED_5-row1-col0.2, LED_6-row1-col1.4
LED_7: LED_6-row1-col1.2, LED_7-row1-col2.4
LED_8: LED_7-row1-col2.2, LED_8-row1-col3.4
LED_9: LED_8-row1-col3.2, LED_9-row1-col4.4
LED_10: LED_9-row1-col4.2, LED_10-row1-col5.4
LED_11: LED_10-row1-col5.2, LED_11-row2-col5.4
LED_12: LED_11-row2-col5.2, LED_12-row2-col4.4
LED_13: LED_12-row2-col4.2, LED_13-row2-col3.4
LED_14: LED_13-row2-col3.2, LED_14-row2-col2.4
LED_15: LED_14-row2-col2.2, LED_15-row2-col1.4
LED_16: LED_15-row2-col1.2, LED_16-row2-col0.4
LED_17: LED_16-row2-col0.2, LED_17-row3-col0.4
LED_18: LED_17-row3-col0.2, LED_18-row3-col1.4
LED_19: LED_18-row3-col1.2, LED_19-row3-col2.4
LED_20: LED_19-row3-col2.2, LED_20-row3-col3.4
LED_21: LED_20-row3-col3.2, LED_21-row3-col4.4
LED_22: LED_21-row3-col4.2, LED_22-row3-col5.4
LED_23: LED_22-row3-col5.2, LED_23-row4-col5.4
LED_24: LED_23-row4-col5.2, LED_24-row4-col4.4
LED_25: LED_24-row4-col4.2, LED_25-row4-col3.4
LED_26: LED_25-row4-col3.2, LED_26-row4-col2.4
LED_27: LED_26-row4-col2.2, LED_27-row4-col1.4
LED_28: LED_27-row4-col1.2, LED_28-row4-col0.4
LED_29: LED_28-row4-col0.2, LED_29-row5-col0.4
LED_30: LED_29-row5-col0.2, LED_30-row5-col1.4
LED_31: LED_30-row5-col1.2, LED_31-row5-col2.4
LED_32: LED_31-row5-col2.2, LED_32-row5-col3.4
LED_33: LED_32-row5-col3.2, LED_33-row5-col5.4
LED_34: LED_33-row5-col5.2, LED_34-row5-col6.4
LED_35: LED_34-row5-col6.2, LED_35-row5-col8.4
LED_36: LED_35-row5-col8.2, LED_36-row5-col9.4
LED_37: LED_36-row5-col9.2, LED_37-row5-col10.4
LED_38: LED_37-row5-col10.2, LED_38-row5-col11.4
LED_39: LED_38-row5-col11.2, LED_39-row5-col14.4
LED_40: LED_39-row5-col14.2, LED_40-row5-col15.4
LED_41: LED_40-row5-col15.2, LED_41-row4-col15.4
LED_42: LED_41-row4-col15.2, LED_42-row4-col14.4
LED_43: LED_42-row4-col14.2, LED_43-row4-col11.4
LED_44: LED_43-row4-col11.2, LED_44-row4-col10.4
LED_45: LED_44-row4-col10.2, LED_45-row4-col9.4
LED_46: LED_45-row4-col9.2, LED_46-row4-col8.4
LED_47: LED_46-row4-col8.2, LED_47-row4-col7.4
LED_48: LED_47-row4-col7.2, LED_48-row4-col6.4
LED_49: LED_48-row4-col6.2, LED_49-row3-col6.4
LED_50: LED_49-row3-col6.2, LED_50-row3-col7.4
LED_51: LED_50-row3-col7.2, LED_51-row3-col8.4
LED_52: LED_51-row3-col8.2, LED_52-row3-col9.4
LED_53: LED_52-row3-col9.2, LED_53-row3-col10.4
LED_54: LED_53-row3-col10.2, LED_54-row3-col11.4
LED_55: LED_54-row3-col11.2, LED_55-row3-col12.4
LED_56: LED_55-row3-col12.2, LED_56-row3-col14.4
LED_57: LED_56-row3-col14.2, LED_57-row3-col15.4
LED_58: LED_57-row3-col15.2, LED_58-row2-col15.4
LED_59: LED_58-row2-col15.2, LED_59-row2-col14.4
LED_60: LED_59-row2-col14.2, LED_60-row2-col13.4
LED_61: LED_60-row2-col13.2, LED_61-row2-col12.4
LED_62: LED_61-row2-col12.2, LED_62-row2-col11.4
LED_63: LED_62-row2-col11.2, LED_63-row2-col10.4
LED_64: LED_63-row2-col10.2, LED_64-row2-col9.4
LED_65: LED_64-row2-col9.2, LED_65-row2-col8.4
LED_66: LED_65-row2-col8.2, LED_66-row2-col7.4
LED_67: LED_66-row2-col7.2, LED_67-row2-col6.4
LED_68: LED_67-row2-col6.2, LED_68-row1-col6.4
LED_69: LED_68-row1-col6.2, LED_69-row1-col7.4
LED_70: LED_69-row1-col7.2, LED_70-row1-col8.4
LED_71: LED_70-row1-col8.2, LED_71-row1-col9.4
LED_72: LED_71-row1-col9.2, LED_72-row1-col10.4
LED_73: LED_72-row1-col10.2, LED_73-row1-col11.4
LED_74: LED_73-row1-col11.2, LED_74-row1-col12.4
LED_75: LED_74-row1-col12.2, LED_75-row1-col13.4
LED_76: LED_75-row1-col13.2, LED_76-row1-col14.4
LED_77: LED_76-row1-col14.2, LED_77-row1-col15.4
LED_78: LED_77-row1-col15.2, LED_78-row0-col15.4
LED_79: LED_78-row0-col15.2, LED_79-row0-col14.4
LED_80: LED_79-row0-col14.2, LED_80-row3-col13.4
LED_81: LED_80-row3-col13.2, LED_81-row0-col13.4
LED_82: LED_81-row0-col13.2, LED_82-row0-col12.4
LED_83: LED_82-row0-col12.2, LED_83-row0-col11.4
LED_84: LED_83-row0-col11.2, LED_84-row0-col9.4
LED_85: LED_84-row0-col9.2, LED_85-row0-col8.4
LED_86: LED_85-row0-col8.2, LED_86-row0-col7.4
LED_87: LED_86-row0-col7.2, LED_87-row0-col6.4
RAW: C1.1, D1.2, KC1.1, KC2.1, KC3.1, KC4.1, KC5.1, KC6.1, KC7.1, KC8.1, KC9.1, KC10.1, KC11.1, KC12.1, KC13.1, KC14.1, KC15.1, KC16.1, KC17.1, KC18.1, KC19.1, KC20.1, KC21.1, KC22.1, KC23.1, KC24.1, KC25.1, KC26.1, KC27.1, KC28.1, KC29.1, KC30.1, KC31.1, KC32.1, KC33.1, KC34.1, KC35.1, KC36.1, KC37.1, KC38.1, KC39.1, KC40.1, KC41.1, KC42.1, KC43.1, KC44.1, KC45.1, KC46.1, KC47.1, KC48.1, KC49.1, KC50.1, KC51.1, KC52.1, KC53.1, KC54.1, KC55.1, KC56.1, KC57.1, KC58.1, KC59.1, KC60.1, KC61.1, KC62.1, KC63.1, KC64.1, KC65.1, KC66.1, KC67.1, KC68.1, KC69.1, KC70.1, KC71.1, KC72.1, KC73.1, KC74.1, KC75.1, KC76.1, KC77.1, KC78.1, KC79.1, KC80.1, KC81.1, KC82.1, KC83.1, KC84.1, KC85.1, KC86.1, KC87.1, LED_1-row0-col4.1, LED_2-row0-col3.1, LED_3-row0-col2.1, LED_4-row0-col0.1, LED_5-row1-col0.1, LED_6-row1-col1.1, LED_7-row1-col2.1, LED_8-row1-col3.1, LED_9-row1-col4.1, LED_10-row1-col5.1, LED_11-row2-col5.1, LED_12-row2-col4.1, LED_13-row2-col3.1, LED_14-row2-col2.1, LED_15-row2-col1.1, LED_16-row2-col0.1, LED_17-row3-col0.1, LED_18-row3-col1.1, LED_19-row3-col2.1, LED_20-row3-col3.1, LED_21-row3-col4.1, LED_22-row3-col5.1, LED_23-row4-col5.1, LED_24-row4-col4.1, LED_25-row4-col3.1, LED_26-row4-col2.1, LED_27-row4-col1.1, LED_28-row4-col0.1, LED_29-row5-col0.1, LED_30-row5-col1.1, LED_31-row5-col2.1, LED_32-row5-col3.1, LED_33-row5-col5.1, LED_34-row5-col6.1, LED_35-row5-col8.1, LED_36-row5-col9.1, LED_37-row5-col10.1, LED_38-row5-col11.1, LED_39-row5-col14.1, LED_40-row5-col15.1, LED_41-row4-col15.1, LED_42-row4-col14.1, LED_43-row4-col11.1, LED_44-row4-col10.1, LED_45-row4-col9.1, LED_46-row4-col8.1, LED_47-row4-col7.1, LED_48-row4-col6.1, LED_49-row3-col6.1, LED_50-row3-col7.1, LED_51-row3-col8.1, LED_52-row3-col9.1, LED_53-row3-col10.1, LED_54-row3-col11.1, LED_55-row3-col12.1, LED_56-row3-col14.1, LED_57-row3-col15.1, LED_58-row2-col15.1, LED_59-row2-col14.1, LED_60-row2-col13.1, LED_61-row2-col12.1, LED_62-row2-col11.1, LED_63-row2-col10.1, LED_64-row2-col9.1, LED_65-row2-col8.1, LED_66-row2-col7.1, LED_67-row2-col6.1, LED_68-row1-col6.1, LED_69-row1-col7.1, LED_70-row1-col8.1, LED_71-row1-col9.1, LED_72-row1-col10.1, LED_73-row1-col11.1, LED_74-row1-col12.1, LED_75-row1-col13.1, LED_76-row1-col14.1, LED_77-row1-col15.1, LED_78-row0-col15.1, LED_79-row0-col14.1, LED_80-row3-col13.1, LED_81-row0-col13.1, LED_82-row0-col12.1, LED_83-row0-col11.1, LED_84-row0-col9.1, LED_85-row0-col8.1, LED_86-row0-col7.1, LED_87-row0-col6.1, MCU1.24
RAWD: D1.1, KC88.1, LED_0-row0-col5.1
RST: MCU1.22, SW1.2
VCC: C2.1, C3.1, DIP1.6, DIP1.16, DIP2.16, MCU1.21
arrows_left_bottom: KD38.1, KSW38.2
arrows_left_top: KD82.1, KSW82.2
arrows_right_bottom: KD39.1, KSW39.2
arrows_right_top: KD83.1, KSW83.2
col0: DIP1.15, KSW1.1, KSW2.1, KSW3.1, KSW44.1, KSW45.1, KSW46.1
col1: DIP1.14, KSW4.1, KSW5.1, KSW6.1, KSW47.1, KSW48.1, SCR1.S1
col2: DIP1.13, KSW7.1, KSW8.1, KSW9.1, KSW49.1, KSW50.1, KSW51.1
col3: DIP1.12, KSW10.1, KSW11.1, KSW12.1, KSW52.1, KSW53.1, KSW54.1
col4: DIP1.11, KSW13.1, KSW14.1, KSW55.1, KSW56.1, KSW57.1, ROT1.1
col5: DIP1.10, KSW15.1, KSW16.1, KSW17.1, KSW58.1, KSW59.1, KSW88.1
col6: DIP1.9, KSW18.1, KSW19.1, KSW20.1, KSW60.1, KSW61.1, KSW62.1
col7: DIP1.7, KSW21.1, KSW22.1, KSW63.1, KSW64.1, KSW65.1
col8: DIP2.15, KSW23.1, KSW24.1, KSW25.1, KSW66.1, KSW67.1, KSW68.1
col9: DIP2.14, KSW26.1, KSW27.1, KSW28.1, KSW69.1, KSW70.1, KSW71.1
col10: DIP2.13, KSW29.1, KSW30.1, KSW31.1, KSW72.1, KSW73.1
col11: DIP2.12, KSW32.1, KSW33.1, KSW34.1, KSW74.1, KSW75.1, KSW76.1
col12: DIP2.11, KSW35.1, KSW36.1, KSW77.1, KSW78.1
col13: DIP2.10, KSW37.1, KSW79.1, KSW80.1, KSW81.1
col14: DIP2.9, KSW42.1, KSW82.1, KSW83.1, KSW84.1, KSW85.1, KSW86.1
col15: DIP2.7, KSW38.1, KSW39.1, KSW40.1, KSW41.1, KSW43.1, KSW87.1
encA: MCU1.14, ROT1.A
encC: MCU1.13, ROT1.C
enc_to: D3.1, ROT1.2
matrixl_index_bottom: KD55.1, KSW55.2
matrixl_index_func: KD57.1, KSW57.2
matrixl_index_home: KD13.1, KSW13.2
matrixl_index_num: KD14.1, KSW14.2
matrixl_index_top: KD56.1, KSW56.2
matrixl_inner_bottom: KD58.1, KSW58.2
matrixl_inner_func: KD88.1, KSW88.2
matrixl_inner_home: KD16.1, KSW16.2
matrixl_inner_mod: KD15.1, KSW15.2
matrixl_inner_num: KD17.1, KSW17.2
matrixl_inner_top: KD59.1, KSW59.2
matrixl_middle_bottom: KD52.1, KSW52.2
matrixl_middle_func: KD54.1, KSW54.2
matrixl_middle_home: KD11.1, KSW11.2
matrixl_middle_mod: KD10.1, KSW10.2
matrixl_middle_num: KD12.1, KSW12.2
matrixl_middle_top: KD53.1, KSW53.2
matrixl_outer_bottom: KD44.1, KSW44.2
matrixl_outer_func: KD46.1, KSW46.2
matrixl_outer_home: KD2.1, KSW2.2
matrixl_outer_mod: KD1.1, KSW1.2
matrixl_outer_num: KD3.1, KSW3.2
matrixl_outer_top: KD45.1, KSW45.2
matrixl_pinky_bottom: KD47.1, KSW47.2
matrixl_pinky_home: KD5.1, KSW5.2
matrixl_pinky_mod: KD4.1, KSW4.2
matrixl_pinky_num: KD6.1, KSW6.2
matrixl_pinky_top: KD48.1, KSW48.2
matrixl_ring_bottom: KD49.1, KSW49.2
matrixl_ring_func: KD51.1, KSW51.2
matrixl_ring_home: KD8.1, KSW8.2
matrixl_ring_mod: KD7.1, KSW7.2
matrixl_ring_num: KD9.1, KSW9.2
matrixl_ring_top: KD50.1, KSW50.2
matrixr_index_bottom: KD63.1, KSW63.2
matrixr_index_func: KD65.1, KSW65.2
matrixr_index_home: KD21.1, KSW21.2
matrixr_index_num: KD22.1, KSW22.2
matrixr_index_top: KD64.1, KSW64.2
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

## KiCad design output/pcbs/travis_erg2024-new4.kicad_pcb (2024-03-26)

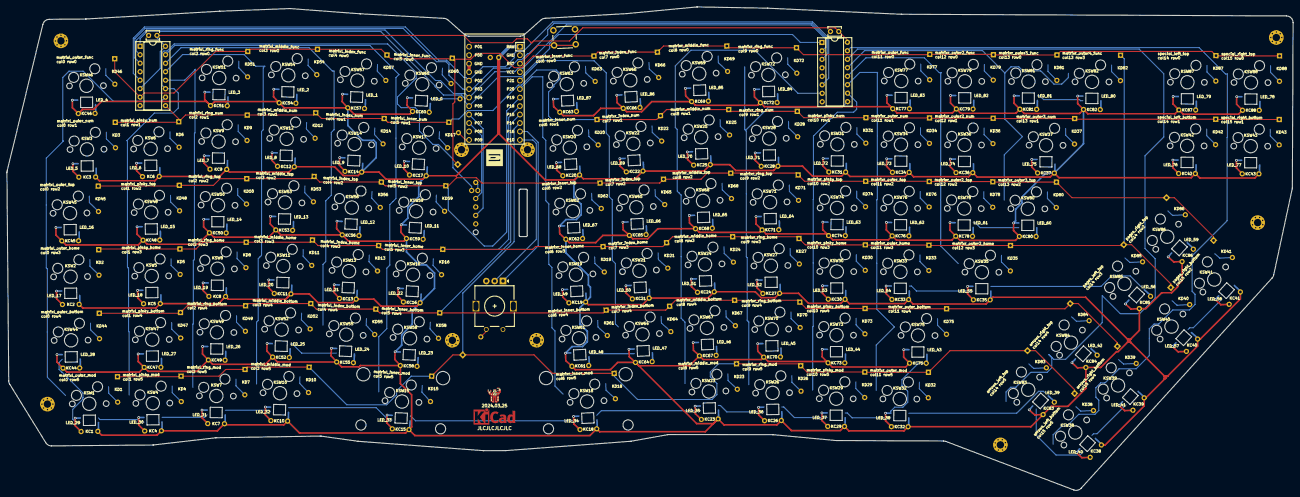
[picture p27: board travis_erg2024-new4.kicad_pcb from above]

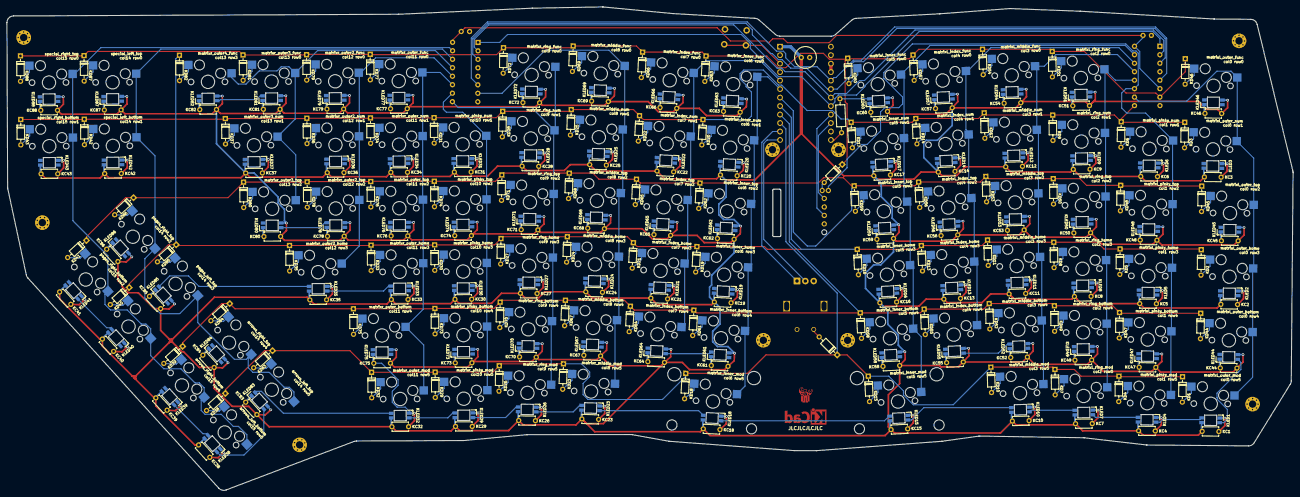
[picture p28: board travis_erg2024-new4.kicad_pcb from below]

Board: 2 copper layers, 385.3 x 144.8 mm, 377 parts (268 on the bottom side), 210 nets.

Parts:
C1: C_Radial_D6.3mm_H11.0mm_P2.50mm
C2, C3: C_Disc_D3.8mm_W2.6mm_P2.50mm
D1, D2: 1N4148; Diode_DO-35
DIP1, DIP2: DIP-16_W7.62mm_Socket
HOLE1, HOLE2, HOLE3, HOLE4, HOLE5, HOLE6, HOLE7, HOLE8, HOLE9: MountingHole_2.2mm_M2_Pad_Via
KC1, KC2, KC3, KC4, KC5, KC6, KC7, KC8, KC9, KC10, KC11, KC12, KC13, KC14, KC15, KC16, KC17, KC18, KC19, KC20, KC21, KC22, KC23, KC24, KC25, KC26, KC27, KC28, KC29, KC30, KC31, KC32, KC33, KC34, KC35, KC36, KC37, KC38, KC39, KC40, KC41, KC42, KC43, KC44, KC45, KC46, KC47, KC48, KC49, KC50, KC51, KC52, KC53, KC54, KC55, KC56, KC57, KC58, KC59, KC60, KC61, KC62, KC63, KC64, KC65, KC66, KC67, KC68, KC69, KC70, KC71, KC72, KC73, KC74, KC75, KC76, KC77, KC78, KC79, KC80, KC81, KC82, KC83, KC84, KC85, KC86, KC87, KC88: 104; C_Disc_D4.7mm_W2.5mm_P5.00mm
KD1, KD2, KD3, KD4, KD5, KD6, KD7, KD8, KD9, KD10, KD11, KD12, KD13, KD14, KD15, KD16, KD17, KD18, KD19, KD20, KD21, KD22, KD23, KD24, KD25, KD26, KD27, KD28, KD29, KD30, KD31, KD32, KD33, KD34, KD35, KD36, KD37, KD38, KD39, KD40, KD41, KD42, KD43, KD44, KD45, KD46, KD47, KD48, KD49, KD50, KD51, KD52, KD53, KD54, KD55, KD56, KD57, KD58, KD59, KD60, KD61, KD62, KD63, KD64, KD65, KD66, KD67, KD68, KD69, KD70, KD71, KD72, KD73, KD74, KD75, KD76, KD77, KD78, KD79, KD80, KD81, KD82, KD83, KD84, KD85, KD86, KD87, KD88: 1N4148; Diode_DO-35
KLED1, KLED2, KLED3, KLED4, KLED5, KLED6, KLED7, KLED8, KLED9, KLED10, KLED11, KLED12, KLED13, KLED14, KLED15, KLED16, KLED17, KLED18, KLED19, KLED20, KLED21, KLED22, KLED23, KLED24, KLED25, KLED26, KLED27, KLED28, KLED29, KLED30, KLED31, KLED32, KLED33, KLED34, KLED35, KLED36, KLED37, KLED38, KLED39, KLED40, KLED41, KLED42, KLED43, KLED44, KLED45, KLED46, KLED47, KLED48, KLED49, KLED50, KLED51, KLED52, KLED53, KLED54, KLED55, KLED56, KLED57, KLED58, KLED59, KLED60, KLED61, KLED62, KLED63, KLED64, KLED65, KLED66, KLED67, KLED68, KLED69, KLED70, KLED71, KLED72, KLED73, KLED74, KLED75, KLED76, KLED77, KLED78, KLED79, KLED80, KLED81, KLED82, KLED83, KLED84, KLED85, KLED86, KLED87, KLED88: SK6812mini-e; led_SK6812mini-e (per-key single-side)
KSW1, KSW2, KSW3, KSW4, KSW5, KSW6, KSW7, KSW8, KSW9, KSW10, KSW11, KSW12, KSW13, KSW14, KSW15, KSW16, KSW17, KSW18, KSW19, KSW20, KSW21, KSW22, KSW23, KSW24, KSW25, KSW26, KSW27, KSW28, KSW29, KSW30, KSW31, KSW32, KSW33, KSW34, KSW35, KSW36, KSW37, KSW38, KSW39, KSW40, KSW41, KSW42, KSW43, KSW44, KSW45, KSW46, KSW47, KSW48, KSW49, KSW50, KSW51, KSW52, KSW53, KSW54, KSW55, KSW56, KSW57, KSW58, KSW59, KSW60, KSW61, KSW62, KSW63, KSW64, KSW65, KSW66, KSW67, KSW68, KSW69, KSW70, KSW71, KSW72, KSW73, KSW74, KSW75, KSW76, KSW77, KSW78, KSW79, KSW80, KSW81, KSW82, KSW83, KSW84, KSW85, KSW86, KSW87, KSW88: Kailh MX Switch Sockets; MX
LOGO1: ergogen
LOGO2: travis
MCU1: ProMicro
R1: R_Axial_DIN0207_L6.3mm_D2.5mm_P10.16mm_Horizontal
ROT1: rotary_encoder
STAB2u1, STAB2u2: Stabilizer_MX_2.00u
SW1: SW_PUSH_6mm_H4.3mm
SYM1: KiCad-Logo_5mm_Copper

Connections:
GND: C1.2, C2.2, C3.2, DIP1.4, DIP1.8, DIP2.4, DIP2.5, DIP2.8, KC1.2, KC2.2, KC3.2, KC4.2, KC5.2, KC6.2, KC7.2, KC8.2, KC9.2, KC10.2, KC11.2, KC12.2, KC13.2, KC14.2, KC15.2, KC16.2, KC17.2, KC18.2, KC19.2, KC20.2, KC21.2, KC22.2, KC23.2, KC24.2, KC25.2, KC26.2, KC27.2, KC28.2, KC29.2, KC30.2, KC31.2, KC32.2, KC33.2, KC34.2, KC35.2, KC36.2, KC37.2, KC38.2, KC39.2, KC40.2, KC41.2, KC42.2, KC43.2, KC44.2, KC45.2, KC46.2, KC47.2, KC48.2, KC49.2, KC50.2, KC51.2, KC52.2, KC53.2, KC54.2, KC55.2, KC56.2, KC57.2, KC58.2, KC59.2, KC60.2, KC61.2, KC62.2, KC63.2, KC64.2, KC65.2, KC66.2, KC67.2, KC68.2, KC69.2, KC70.2, KC71.2, KC72.2, KC73.2, KC74.2, KC75.2, KC76.2, KC77.2, KC78.2, KC79.2, KC80.2, KC81.2, KC82.2, KC83.2, KC84.2, KC85.2, KC86.2, KC87.2, KC88.2, KLED1.3, KLED2.3, KLED3.3, KLED4.3, KLED5.3, KLED6.3, KLED7.3, KLED8.3, KLED9.3, KLED10.3, KLED11.3, KLED12.3, KLED13.3, KLED14.3, KLED15.3, KLED16.3, KLED17.3, KLED18.3, KLED19.3, KLED20.3, KLED21.3, KLED22.3, KLED23.3, KLED24.3, KLED25.3, KLED26.3, KLED27.3, KLED28.3, KLED29.3, KLED30.3, KLED31.3, KLED32.3, KLED33.3, KLED34.3, KLED35.3, KLED36.3, KLED37.3, KLED38.3, KLED39.3, KLED40.3, KLED41.3, KLED42.3, KLED43.3, KLED44.3, KLED45.3, KLED46.3, KLED47.3, KLED48.3, KLED49.3, KLED50.3, KLED51.3, KLED52.3, KLED53.3, KLED54.3, KLED55.3, KLED56.3, KLED57.3, KLED58.3, KLED59.3, KLED60.3, KLED61.3, KLED62.3, KLED63.3, KLED64.3, KLED65.3, KLED66.3, KLED67.3, KLED68.3, KLED69.3, KLED70.3, KLED71.3, KLED72.3, KLED73.3, KLED74.3, KLED75.3, KLED76.3, KLED77.3, KLED78.3, KLED79.3, KLED80.3, KLED81.3, KLED82.3, KLED83.3, KLED84.3, KLED85.3, KLED86.3, KLED87.3, KLED88.3, MCU1.2, MCU1.15, MCU1.16, ROT1.B, SW1.1
LED: MCU1.24, R1.1
LED_0: KLED60.4, R1.2
LED_1: KLED57.4, KLED60.2
LED_2: KLED54.4, KLED57.2
LED_3: KLED51.4, KLED54.2
LED_4: KLED46.4, KLED51.2
LED_5: KLED3.4, KLED46.2
LED_6: KLED3.2, KLED6.4
LED_7: KLED6.2, KLED9.4
LED_8: KLED9.2, KLED12.4
LED_9: KLED12.2, KLED14.4
LED_10: KLED14.2, KLED17.4
LED_11: KLED17.2, KLED59.4
LED_12: KLED56.4, KLED59.2
LED_13: KLED53.4, KLED56.2
LED_14: KLED50.4, KLED53.2
LED_15: KLED48.4, KLED50.2
LED_16: KLED45.4, KLED48.2
LED_17: KLED2.4, KLED45.2
LED_18: KLED2.2, KLED5.4
LED_19: KLED5.2, KLED8.4
LED_20: KLED8.2, KLED11.4
LED_21: KLED11.2, KLED13.4
LED_22: KLED13.2, KLED16.4
LED_23: KLED16.2, KLED58.4
LED_24: KLED55.4, KLED58.2
LED_25: KLED52.4, KLED55.2
LED_26: KLED49.4, KLED52.2
LED_27: KLED47.4, KLED49.2
LED_28: KLED44.4, KLED47.2
LED_29: KLED1.4, KLED44.2
LED_30: KLED1.2, KLED4.4
LED_31: KLED4.2, KLED7.4
LED_32: KLED7.2, KLED10.4
LED_33: KLED10.2, KLED15.4
LED_34: KLED15.2, KLED18.4
LED_35: KLED18.2, KLED23.4
LED_36: KLED23.2, KLED26.4
LED_37: KLED26.2, KLED29.4
LED_38: KLED29.2, KLED32.4
LED_39: KLED32.2, KLED83.4
LED_40: KLED38.4, KLED83.2
LED_41: KLED38.2, KLED39.4
LED_42: KLED39.2, KLED84.4
LED_43: KLED75.4, KLED84.2
LED_44: KLED73.4, KLED75.2
LED_45: KLED70.4, KLED73.2
LED_46: KLED67.4, KLED70.2
LED_47: KLED64.4, KLED67.2
LED_48: KLED61.4, KLED64.2
LED_49: KLED19.4, KLED61.2
LED_50: KLED19.2, KLED21.4
LED_51: KLED21.2, KLED24.4
LED_52: KLED24.2, KLED27.4
LED_53: KLED27.2, KLED30.4
LED_54: KLED30.2, KLED33.4
LED_55: KLED33.2, KLED35.4
LED_56: KLED35.2, KLED85.4
LED_57: KLED40.4, KLED85.2
LED_58: KLED40.2, KLED41.4
LED_59: KLED41.2, KLED86.4
LED_60: KLED80.4, KLED86.2
LED_61: KLED78.4, KLED80.2
LED_62: KLED76.4, KLED78.2
LED_63: KLED74.4, KLED76.2
LED_64: KLED71.4, KLED74.2
LED_65: KLED68.4, KLED71.2
LED_66: KLED65.4, KLED68.2
LED_67: KLED62.4, KLED65.2
LED_68: KLED20.4, KLED62.2
LED_69: KLED20.2, KLED22.4
LED_70: KLED22.2, KLED25.4
LED_71: KLED25.2, KLED28.4
LED_72: KLED28.2, KLED31.4
LED_73: KLED31.2, KLED34.4
LED_74: KLED34.2, KLED36.4
LED_75: KLED36.2, KLED37.4
LED_76: KLED37.2, KLED42.4
LED_77: KLED42.2, KLED43.4
LED_78: KLED43.2, KLED88.4
LED_79: KLED87.4, KLED88.2
LED_80: KLED82.4, KLED87.2
LED_81: KLED81.4, KLED82.2
LED_82: KLED79.4, KLED81.2
LED_83: KLED77.4, KLED79.2
LED_84: KLED72.4, KLED77.2
LED_85: KLED69.4, KLED72.2
LED_86: KLED66.4, KLED69.2
LED_87: KLED63.4, KLED66.2
RAW: C1.1, KC1.1, KC2.1, KC3.1, KC4.1, KC5.1, KC6.1, KC7.1, KC8.1, KC9.1, KC10.1, KC11.1, KC12.1, KC13.1, KC14.1, KC15.1, KC16.1, KC17.1, KC18.1, KC19.1, KC20.1, KC21.1, KC22.1, KC23.1, KC24.1, KC25.1, KC26.1, KC27.1, KC28.1, KC29.1, KC30.1, KC31.1, KC32.1, KC33.1, KC34.1, KC35.1, KC36.1, KC37.1, KC38.1, KC39.1, KC40.1, KC41.1, KC42.1, KC43.1, KC44.1, KC45.1, KC46.1, KC47.1, KC48.1, KC49.1, KC50.1, KC51.1, KC52.1, KC53.1, KC54.1, KC55.1, KC56.1, KC57.1, KC58.1, KC59.1, KC60.1, KC61.1, KC62.1, KC63.1, KC64.1, KC65.1, KC66.1, KC67.1, KC68.1, KC69.1, KC70.1, KC71.1, KC72.1, KC73.1, KC74.1, KC75.1, KC76.1, KC77.1, KC78.1, KC79.1, KC80.1, KC81.1, KC82.1, KC83.1, KC84.1, KC85.1, KC86.1, KC87.1, KC88.1, KLED1.1, KLED2.1, KLED3.1, KLED4.1, KLED5.1, KLED6.1, KLED7.1, KLED8.1, KLED9.1, KLED10.1, KLED11.1, KLED12.1, KLED13.1, KLED14.1, KLED15.1, KLED16.1, KLED17.1, KLED18.1, KLED19.1, KLED20.1, KLED21.1, KLED22.1, KLED23.1, KLED24.1, KLED25.1, KLED26.1, KLED27.1, KLED28.1, KLED29.1, KLED30.1, KLED31.1, KLED32.1, KLED33.1, KLED34.1, KLED35.1, KLED36.1, KLED37.1, KLED38.1, KLED39.1, KLED40.1, KLED41.1, KLED42.1, KLED43.1, KLED44.1, KLED45.1, KLED46.1, KLED47.1, KLED48.1, KLED49.1, KLED50.1, KLED51.1, KLED52.1, KLED53.1, KLED54.1, KLED55.1, KLED56.1, KLED57.1, KLED58.1, KLED59.1, KLED60.1, KLED61.1, KLED62.1, KLED63.1, KLED64.1, KLED65.1, KLED66.1, KLED67.1, KLED68.1, KLED69.1, KLED70.1, KLED71.1, KLED72.1, KLED73.1, KLED74.1, KLED75.1, KLED76.1, KLED77.1, KLED78.1, KLED79.1, KLED80.1, KLED81.1, KLED82.1, KLED83.1, KLED84.1, KLED85.1, KLED86.1, KLED87.1, KLED88.1, MCU1.1
RST: MCU1.3, SW1.2
VCC: C2.1, C3.1, DIP1.6, DIP1.16, DIP2.16, MCU1.4
arrows_left_bottom: KD38.2, KSW38.2
arrows_left_top: KD83.2, KSW83.2
arrows_right_bottom: KD39.2, KSW39.2
arrows_right_top: KD84.2, KSW84.2
col0: DIP1.10, KSW1.1, KSW2.1, KSW3.1, KSW44.1, KSW45.1, KSW46.1
col1: DIP1.11, KSW4.1, KSW5.1, KSW6.1, KSW47.1, KSW48.1
col2: DIP1.12, KSW7.1, KSW8.1, KSW9.1, KSW49.1, KSW50.1, KSW51.1
col3: DIP1.13, KSW10.1, KSW11.1, KSW12.1, KSW52.1, KSW53.1, KSW54.1
col4: DIP1.14, KSW13.1, KSW14.1, KSW55.1, KSW56.1, KSW57.1, ROT1.1
col5: DIP1.15, KSW15.1, KSW16.1, KSW17.1, KSW58.1, KSW59.1, KSW60.1
col6: KSW18.1, KSW19.1, KSW20.1, KSW61.1, KSW62.1, KSW63.1, MCU1.6
col7: KSW21.1, KSW22.1, KSW64.1, KSW65.1, KSW66.1, MCU1.5
col8: DIP2.7, KSW23.1, KSW24.1, KSW25.1, KSW67.1, KSW68.1, KSW69.1
col9: DIP2.9, KSW26.1, KSW27.1, KSW28.1, KSW70.1, KSW71.1, KSW72.1
col10: DIP2.10, KSW29.1, KSW30.1, KSW31.1, KSW73.1, KSW74.1
col11: DIP2.11, KSW32.1, KSW33.1, KSW34.1, KSW75.1, KSW76.1, KSW77.1
col12: DIP2.12, KSW35.1, KSW36.1, KSW78.1, KSW79.1
col13: DIP2.13, KSW37.1, KSW80.1, KSW81.1, KSW82.1
col14: DIP2.14, KSW42.1, KSW83.1, KSW84.1, KSW85.1, KSW86.1, KSW87.1
col15: DIP2.15, KSW38.1, KSW39.1, KSW40.1, KSW41.1, KSW43.1, KSW88.1
encA: MCU1.11, ROT1.A
encC: MCU1.12, ROT1.C
enc_to: D2.2, ROT1.2
matrixl_index_bottom: KD55.2, KSW55.2
matrixl_index_func: KD57.2, KSW57.2
matrixl_index_home: KD13.2, KSW13.2
matrixl_index_num: KD14.2, KSW14.2
matrixl_index_top: KD56.2, KSW56.2
matrixl_inner_bottom: KD58.2, KSW58.2
matrixl_inner_func: KD60.2, KSW60.2
matrixl_inner_home: KD16.2, KSW16.2
matrixl_inner_mod: KD15.2, KSW15.2
matrixl_inner_num: KD17.2, KSW17.2
matrixl_inner_top: KD59.2, KSW59.2
matrixl_middle_bottom: KD52.2, KSW52.2
matrixl_middle_func: KD54.2, KSW54.2
matrixl_middle_home: KD11.2, KSW11.2
matrixl_middle_mod: KD10.2, KSW10.2
matrixl_middle_num: KD12.2, KSW12.2
matrixl_middle_top: KD53.2, KSW53.2
matrixl_outer_bottom: KD44.2, KSW44.2
matrixl_outer_func: KD46.2, KSW46.2
matrixl_outer_home: KD2.2, KSW2.2
matrixl_outer_mod: KD1.2, KSW1.2
matrixl_outer_num: KD3.2, KSW3.2
matrixl_outer_top: KD45.2, KSW45.2
matrixl_pinky_bottom: KD47.2, KSW47.2
matrixl_pinky_home: KD5.2, KSW5.2
matrixl_pinky_mod: KD4.2, KSW4.2
matrixl_pinky_num: KD6.2, KSW6.2
matrixl_pinky_top: KD48.2, KSW48.2
matrixl_ring_bottom: KD49.2, KSW49.2
matrixl_ring_func: KD51.2, KSW51.2
matrixl_ring_home: KD8.2, KSW8.2
matrixl_ring_mod: KD7.2, KSW7.2
matrixl_ring_num: KD9.2, KSW9.2
matrixl_ring_top: KD50.2, KSW50.2
matrixr_index_bottom: KD64.2, KSW64.2
matrixr_index_func: KD66.2, KSW66.2
matrixr_index_home: KD21.2, KSW21.2
matrixr_index_num: KD22.2, KSW22.2
matrixr_index_top: KD65.2, KSW65.2
matrixr_inner_bottom: KD61.2, KSW61.2
matrixr_inner_func: KD63.2, KSW63.2
matrixr_inner_home: KD19.2, KSW19.2
matrixr_inner_mod: KD18.2, KSW18.2
matrixr_inner_num: KD20.2, KSW20.2
matrixr_inner_top: KD62.2, KSW62.2
matrixr_middle_bottom: KD67.2, KSW67.2
matrixr_middle_func: KD69.2, KSW69.2
matrixr_middle_home: KD24.2, KSW24.2
matrixr_middle_mod: KD23.2, KSW23.2
matrixr_middle_num: KD25.2, KSW25.2
matrixr_middle_top: KD68.2, KSW68.2
matrixr_outer2_func: KD79.2, KSW79.2
matrixr_outer2_home: KD35.2, KSW35.2
matrixr_outer2_num: KD36.2, KSW36.2
matrixr_outer2_top: KD78.2, KSW78.2
matrixr_outer3_func: KD81.2, KSW81.2
matrixr_outer3_num: KD37.2, KSW37.2
matrixr_outer3_top: KD80.2, KSW80.2
matrixr_outer4_func: KD82.2, KSW82.2
matrixr_outer_bottom: KD75.2, KSW75.2
matrixr_outer_func: KD77.2, KSW77.2
matrixr_outer_home: KD33.2, KSW33.2
matrixr_outer_mod: KD32.2, KSW32.2
matrixr_outer_num: KD34.2, KSW34.2
matrixr_outer_top: KD76.2, KSW76.2
matrixr_pinky_bottom: KD73.2, KSW73.2
matrixr_pinky_home: KD30.2, KSW30.2
matrixr_pinky_mod: KD29.2, KSW29.2
matrixr_pinky_num: KD31.2, KSW31.2
matrixr_pinky_top: KD74.2, KSW74.2
matrixr_ring_bottom: KD70.2, KSW70.2
matrixr_ring_func: KD72.2, KSW72.2
matrixr_ring_home: KD27.2, KSW27.2
matrixr_ring_mod: KD26.2, KSW26.2
matrixr_ring_num: KD28.2, KSW28.2
matrixr_ring_top: KD71.2, KSW71.2
mux0: DIP1.1, DIP2.1, MCU1.20
mux1: DIP1.2, DIP2.2, MCU1.19
mux2: DIP1.3, DIP2.3, MCU1.18
mux3: DIP1.5, DIP2.6, MCU1.17
pages_left_bottom: KD40.2, KSW40.2
pages_left_top: KD85.2, KSW85.2
pages_right_bottom: KD41.2, KSW41.2
pages_right_top: KD86.2, KSW86.2
row0: D1.1, DIP1.7, KD46.1, KD51.1, KD54.1, KD57.1, KD60.1, KD63.1, KD66.1, KD69.1, KD72.1, KD77.1, KD79.1, KD81.1, KD87.1, KD88.1
row1: DIP1.9, KD3.1, KD6.1, KD9.1, KD12.1, KD14.1, KD17.1, KD20.1, KD22.1, KD25.1, KD28.1, KD31.1, KD34.1, KD36.1, KD37.1, KD42.1, KD43.1
row2: KD41.1, KD45.1, KD48.1, KD50.1, KD53.1, KD56.1, KD59.1, KD62.1, KD65.1, KD68.1, KD71.1, KD74.1, KD76.1, KD78.1, KD80.1, KD86.1, MCU1.7
row3: KD2.1, KD5.1, KD8.1, KD11.1, KD13.1, KD16.1, KD19.1, KD21.1, KD24.1, KD27.1, KD30.1, KD33.1, KD35.1, KD40.1, KD82.1, KD85.1, MCU1.8
row4: KD39.1, KD44.1, KD47.1, KD49.1, KD52.1, KD55.1, KD58.1, KD61.1, KD64.1, KD67.1, KD70.1, KD73.1, KD75.1, KD84.1, MCU1.9
row5: D2.1, KD1.1, KD4.1, KD7.1, KD10.1, KD15.1, KD18.1, KD23.1, KD26.1, KD29.1, KD32.1, KD38.1, KD83.1, MCU1.10
special_left_bottom: KD42.2, KSW42.2
special_left_top: KD87.2, KSW87.2
special_right_bottom: KD43.2, KSW43.2
special_right_top: KD88.2, KSW88.2

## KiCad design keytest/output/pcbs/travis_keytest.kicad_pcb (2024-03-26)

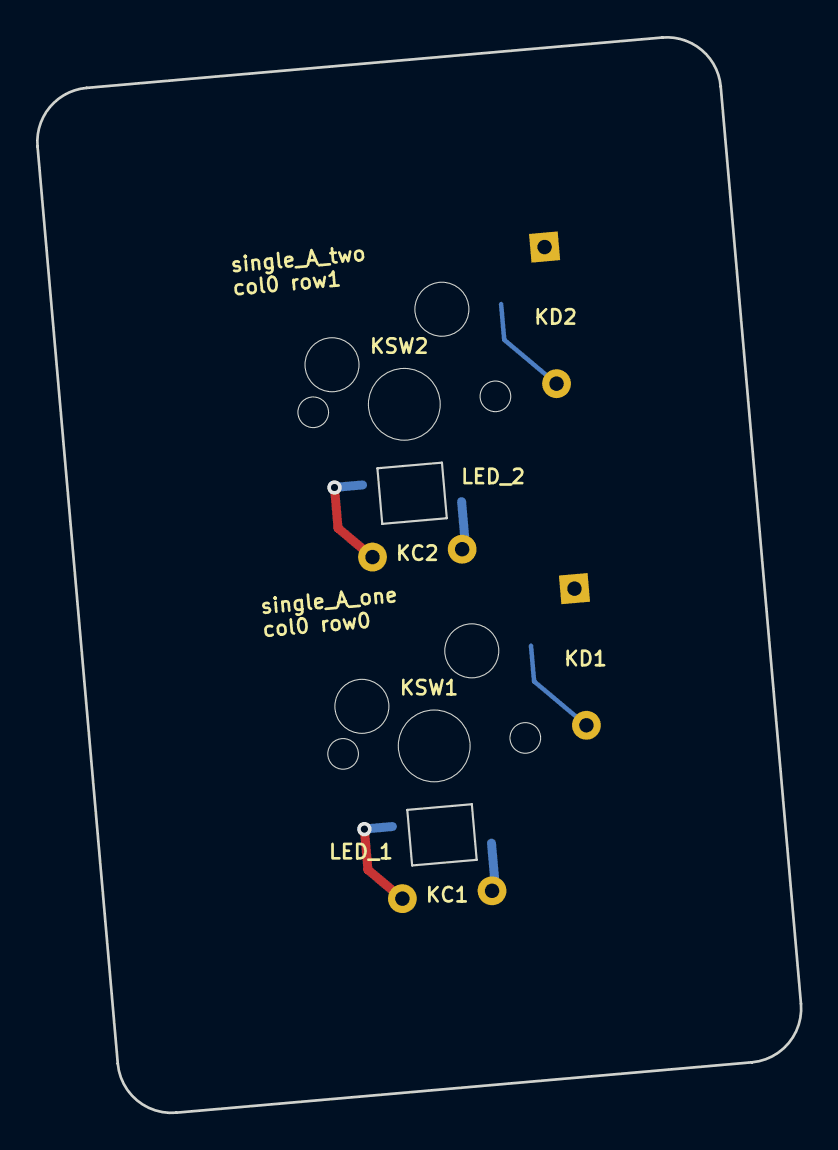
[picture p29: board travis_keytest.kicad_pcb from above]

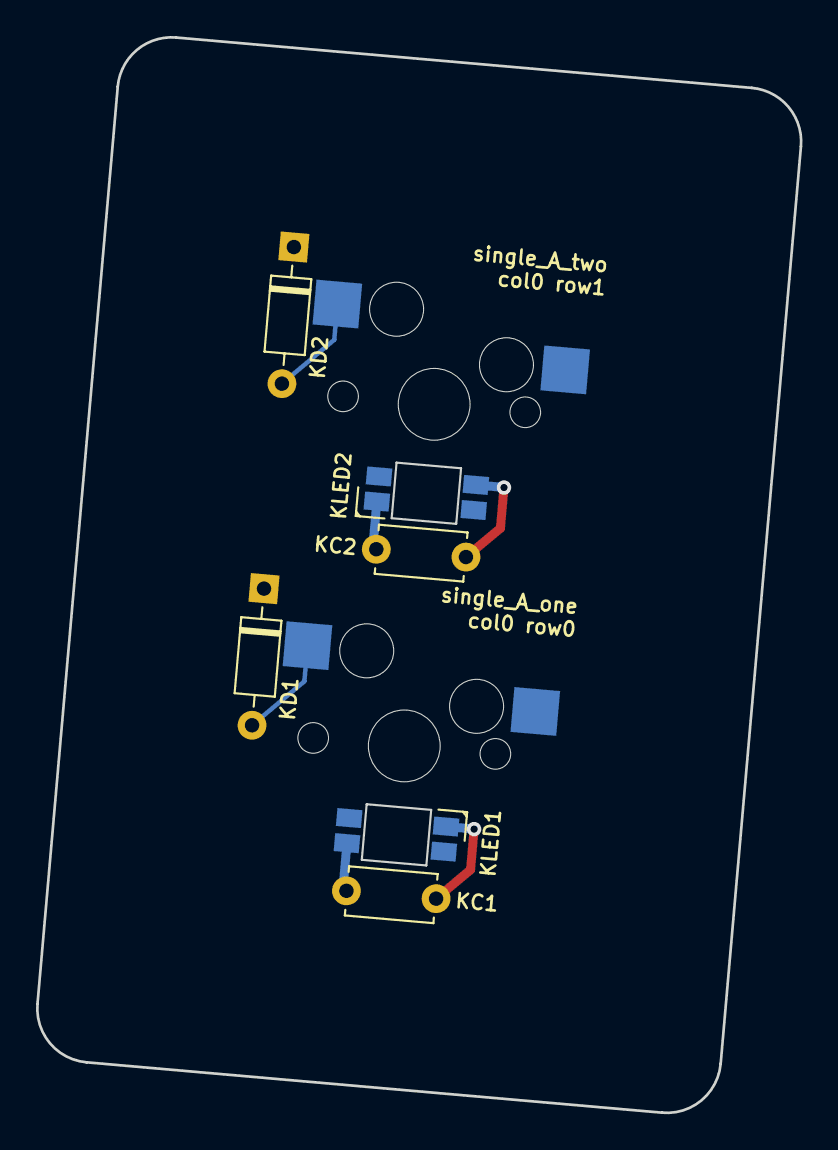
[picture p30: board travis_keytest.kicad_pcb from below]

Board: 2 copper layers, 42.4 x 59.7 mm, 8 parts (6 on the bottom side), 6 nets.

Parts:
KC1, KC2: 104; C_Disc_D4.7mm_W2.5mm_P5.00mm
KD1, KD2: 1N4148; Diode_DO-35
KLED1, KLED2: SK6812mini-e; led_SK6812mini-e (per-key single-side)
KSW1, KSW2: Kailh MX Switch Sockets; MX

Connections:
GND: KC1.2, KC2.2, KLED1.3, KLED2.3
LED_2: KLED1.2, KLED2.4
RAW: KC1.1, KC2.1, KLED1.1, KLED2.1
col0: KSW1.1, KSW2.1
single_A_one: KD1.2, KSW1.2
single_A_two: KD2.2, KSW2.2

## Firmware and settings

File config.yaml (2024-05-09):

meta:
  engine: 4.1.0
  name: "travis-ergogen-2024"
  version: &meta_version "2024.05.07"
  date: "2024-05-07"
  author: 'Travis Hardiman'
  url: &url https://github.com/dieseltravis/travis-ergogen-2024
  tags: [ "ergogen", "promicro", "keyboard", "cherrymx", "hotswap", "rgb", "kb2040", "SN74HC138N" ]
units:
  pp: U + 2
  # outer perimeter of board
  op: U + 6
  # STL wall width
  wall3d: 1
  # stl padding
  stlp: U + 6 + (2 * wall3d)
  screwSize: 1.5
  standoffSize: 2.5
  standoffHeight: 4.0
  # plate switch width
  pw: 14
  boardThick: 1.6
  # spacebar settings
  #spacew: 3U
  spacew: 2.75U
  #spaceshiftx: 0.6
  spaceshiftx: -1.5
  # stab Y adjust
  staby: 0.62
  # stabs
  stabilizer_width: 7 
  stabilizer_height: 16
  stabilizer_offset: 0 # This means south stabs, use `orient` to rotate them for north facing scenarios
  stabilizer_spacing_3u: u * ((3 - 1) / 2)
  stabilizer_spacing_2u: 23.86 / 2 # 0.94in / 2
points:
  zones:
    matrixl:
      anchor:
        # move the PCB into view for KiCad
        shift: [40, -200]
        #rotate: 0
      key:
        padding: U
        spread: U
        splay: 0
        tags: 
          - key
      columns:
        outer:
          key:
            splay: 0
            column_net: col0
          rows:
            mod.key.led_next: LED_30
            mod.key.led_this: LED_29
            bottom:
              shift: [-pp / 4, 0]
              width: 1.5U
            bottom.key.led_next: LED_29
            bottom.key.led_this: LED_28
            home.width: 1.5U
            home.key.led_next: LED_18
            home.key.led_this: LED_17
            top.width: 1.5U
            top.key.led_next: LED_17
            top.key.led_this: LED_16
            num.shift: [pp / 4, 0]
            num.key.led_next: LED_6
            num.key.led_this: LED_5
            func.key.led_next: LED_5
            func.key.led_this: LED_4
        pinky:
          key:
            splay: 0
            column_net: col1
          rows:
            mod.key.led_next: LED_31
            mod.key.led_this: LED_30
            bottom.shift: [0, 0]
            bottom.key.led_next: LED_28
            bottom.key.led_this: LED_27
            home.key.led_next: LED_19
            home.key.led_this: LED_18
            top.key.led_next: LED_16
            top.key.led_this: LED_15
            num.shift: [0, 0]
            num.key.led_next: LED_7
            num.key.led_this: LED_6
            func.skip: true
        ring:
          key:
            splay: -1
            stagger: 2
            #shift: [0.2, 0]
            column_net: col2
          rows:
            mod.key.led_next: LED_32
            mod.key.led_this: LED_31
            bottom.shift: [0, 0]
            bottom.key.led_next: LED_27
            bottom.key.led_this: LED_26
            home.key.led_next: LED_20
            home.key.led_this: LED_19
            top.key.led_next: LED_15
            top.key.led_this: LED_14
            num.shift: [0, 0]
            num.key.led_next: LED_8
            num.key.led_this: LED_7
            func.key.led_next: LED_4
            func.key.led_this: LED_3
        middle:
          key:
            splay: -1
            stagger: 1
            #shift: [0.4, 0]
            column_net: col3
          rows:
            mod.key.led_next: LED_33
            mod.key.led_this: LED_32
            bottom.shift: [0, 0]
            bottom.key.led_next: LED_26
            bottom.key.led_this: LED_25
            home.key.led_next: LED_21
            home.key.led_this: LED_20
            top.key.led_next: LED_14
            top.key.led_this: LED_13
            num.shift: [0, 0]
            num.key.led_next: LED_9
            num.key.led_this: LED_8
            func.key.led_next: LED_3
            func.key.led_this: LED_2
        index:
          key:
            splay: -1
            stagger: -1
            #shift: [0.2, 0]
            column_net: col4
          rows:
            mod.skip: true
            bottom.key.led_next: LED_25
            bottom.key.led_this: LED_24
            home.key.led_next: LED_22
            home.key.led_this: LED_21
            top.key.led_next: LED_13
            top.key.led_this: LED_12
            num.shift: [0, 0]
            num.key.led_next: LED_10
            num.key.led_this: LED_9
            func.key.led_next: LED_2
            func.key.led_this: LED_1
        inner:
          key:
            stagger: -0.25
            splay: -0.25
            column_net: col5
          rows:
            mod:
              shift: [spaceshiftx, 0]
              width: spacew
              tags: [key, 2u_stabilizers, row_odd]
            mod.key.led_next: LED_34
            mod.key.led_this: LED_33
            bottom:
              shift: [-spaceshiftx, 0]
            bottom.key.led_next: LED_24
            bottom.key.led_this: LED_23
            home.key.led_next: LED_23
            home.key.led_this: LED_22
            top.key.led_next: LED_12
            top.key.led_this: LED_11
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

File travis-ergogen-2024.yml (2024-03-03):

units:
  p: u + 2
  pp: U + 2
  op: u + 4
points:
  zones:
    matrixl:
      anchor:
        shift: [28, -175]
      #key:
      #  padding: U
      #  spread: U
      columns:
        outer:
          rows:
            bottom:
              #shift: [U/2, 0]
              width: 2u
            home.width: 2U
            top.width: 2U
            #num.shift: [-U/2, 0]
        pinky:
          rows:
            bottom.shift: [U/2, 0]
            num.shift: [-U/2, 0]
            func.skip: true
        ring:
          rows:
            bottom.shift: [U/2, 0]
            num.shift: [-U/2, 0]
        middle:
          rows:
            bottom.shift: [U/2, 0]
            num.shift: [-U/2, 0]
        index:
          rows:
            mod:
              shift: [U, 0]
              width: 3u
            bottom.shift: [-U/2, 0]
            num.shift: [-U/2, 0]
        inner:
          rows:
            mod.skip: true
            bottom.shift: [U/2, 0]
            num.shift: [-U/2, 0]
      rows:
        mod:
        bottom:
        home:
        top:
        num:
        func:
    matrixr:
      anchor:
        ref: matrixl_inner_mod
        shift: [3.25U, 0]
      columns:
        inner:
          rows.mod:
            width: 3u
        index:
          rows.mod.skip: true
        middle:
          rows.mod.skip: true
        ring:
          rows.mod.shift: [-U, 0]
          rows.bottom.shift: [U/2, 0]
        pinky:
          rows.mod.shift: [-U, 0]
          rows.bottom.shift: [U/2, 0]
          rows.func.skip: true
        outer:
          rows.mod.shift: [-U, 0]
          rows.bottom:
            shift: [U, 0]
            width: 2u
          rows.home.shift: [-U/2, 0]
        outer2:
          rows.mod.shift: [-U, 0]
          rows.bottom.skip: true
          rows.home:
            shift: [1.5U, 0]
            width: 2u
          rows.top.shift: [-U/2, 0]
        outer3:
          rows.mod.skip: true
          rows.bottom.skip: true
          rows.home.skip: true
          rows.num:
            shift: [U/2, 0]
            width: 2u
          rows.func:
            shift: [-U, 0]
        outer4:
          rows.mod.skip: true
          rows.bottom.skip: true
          rows.home.skip: true
          rows.top.skip: true
          rows.num.skip: true
      rows:
        mod:
        bottom:
          shift: [-U/2, 0]
        home:
        top:
        num:
        func:
          shift: [-U/2, 0]
    arrows:
      anchor:
        ref: matrixr_inner_mod
        shift: [7.8U, 0.1U]
        rotate: 45
      columns:
        one:
        two:
      rows:
        a:
        b:
    pages:
      anchor:
        ref: arrows_two_a
        shift: [1.35U, -0.7U]
      columns:
        one:
        two:
      rows:
        a:
        b:
    special:
      anchor:
        ref: matrixr_outer4_num
        shift: [1.5U, 0U]
      columns:
        left:
        mid:
        right:
      rows:
        bottom:
        top:
outlines:
  raw:
    - what: rectangle
      where: true
      bound: true
      size: [pp, pp]
  keys:
    - what: rectangle
      where: true
      bound: false
      size: [u-0.5,u-0.5]
  board:
    - what: polygon
      operation: stack
      points:
        - ref: matrixl_outer_func
          shift: [-0.5op, 0.5op]
        - ref: special_right_top
          shift: [0.5op, 0.5op]
        - ref: pages_two_a
          shift: [0.5op, -0.5op]
        - ref: pages_one_a
          shift: [-0.5op, -0.5op]
        #- ref: arrows_two_a
        #  shift: [0.5op, -0.5op]
        - ref: arrows_one_a
          shift: [-0.5op, -0.5op]
        - ref: matrixr_outer2_mod
          shift: [0.5op, -0.5op]
        - ref: matrixl_outer_mod
          shift: [-0.5op, -0.5op]
      fillet: 2
  combo:
    - name: board
    - operation: subtract
      name: keys
pcbs:
  tutorial:
    outlines:
      main:
        outline: board
    footprints:
      mx_hotswap:
        what: mx
        where: true
        params:
          keycaps: true
          reverse: false
          hotswap: true
          from: "{{column_net}}"
          to: "{{colrow}}"
      diode:
        what: diode
        where: true
        params:
          from: "{{colrow}}"
          to: "{{row_net}}"
        adjust:
          shift: [0, -5]
      promicro:
        what: promicro
        params:
          orientation: "down"
        where:
          ref.aggregate.parts: [matrixl_inner_func, matrixr_inner_func]
          shift: [0,-4]
          rotate: -90
      reset:
        what: button
        params:
          from: GND
          to: RST
        where:
          ref.aggregate.parts: [matrixr_outer4_func, special_left_top]
          shift: [0, 0]
case:

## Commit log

2024-03-02 first output
    [demo.dxf]
2024-03-02 next output
    [demo.dxf]
2024-03-03 next output2
    [demo.dxf]
2024-03-03 arrows, pages, others
    [demo.dxf]
2024-03-03 more outlines
    [board.dxf, combo.dxf, raw.dxf]
2024-03-03 padded outlines
    [board.dxf, combo.dxf]
2024-03-03 tutorial pcb
    [board.dxf, combo.dxf, keys.dxf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]
2024-03-03 pcb shifted
    [board.dxf, combo.dxf, demo.dxf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]
2024-03-03 pcb with pro micro
    [board.dxf, combo.dxf, keys.dxf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]
2024-03-03 reset button
    [board.dxf, combo.dxf, keys.dxf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]
2024-03-03 added case holes
    [board.dxf, combo.dxf, keys.dxf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]
2024-03-03 moved case holes
    [tutorial.kicad_pcb]
2024-03-03 bottom stl
    [bottom.stl]
2024-03-03 case finished
    [case.stl, mounting.dxf, standoff.dxf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]
2024-03-04 added todos
    [tutorial.kicad_pcb]
2024-03-05 init node
    [board.dxf, board3d.dxf, bottom.stl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]
2024-03-05 added dip-16
    [tutorial.kicad_pcb]
2024-03-05 updated keys to ortho
    [board.dxf, board3d.dxf, bottom.stl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]
2024-03-06 new footprint for caps
    [bottom.stl, case.stl, travis_erg2024.kicad_pcb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]
2024-03-06 splay & stagger
    [3u_stabilizer.dxf, board.dxf, board3d.dxf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]
2024-03-06 tweak right side
    [board.dxf, board3d.dxf, bottom.stl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]
2024-03-07 plate, holes, diodes
    [case.stl, mounting.dxf, plate.dxf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]
2024-03-07 outline adjust
    [board.dxf, board3d.dxf, bottom.stl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]
2024-03-08 added stabs
    [travis_erg2024.kicad_pcb]
2024-03-08 try alt stab
    [travis_erg2024.kicad_pcb]
2024-03-08 3d adjustments
    [board3d.dxf, bottom.stl, case.stl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]
2024-03-08 3d plate
    [plate3d.stl]
2024-03-08 hole updates
    [case.stl, mounting.dxf, plate.dxf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]
2024-03-08 tweak splay
    [board.dxf, board3d.dxf, case.stl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]
2024-03-08 tweak rotation, position
    [board.dxf, board3d.dxf, case.stl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]
2024-03-09 updated plate
    [board.dxf, board3d.dxf, bottom.stl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]
2024-03-09 added rgb leds, moved diodes
    [travis_erg2024.kicad_pcb]
2024-03-09 moved switch
    [travis_erg2024.kicad_pcb]
2024-03-11 added datasheets, caps, resistor
    [travis_erg2024.kicad_pcb]
2024-03-12 alternate led rotate
    [travis_erg2024.kicad_pcb]
2024-03-12 cap alignment fixed
    [travis_erg2024.kicad_pcb]
2024-03-13 mapping rows, cols, leds progress
    [3u_stabilizer.dxf, travis_erg2024.kicad_pcb]
2024-03-13 added raw power to leds
    [travis_erg2024.kicad_pcb]
2024-03-14 col & row nets
    [travis_erg2024.kicad_pcb]
2024-03-14 new switch footprint
    [travis_erg2024.kicad_pcb]
2024-03-15 matrix l leds
    [travis_erg2024.kicad_pcb]
2024-03-16 right half leds
    [combo.dxf, keyholes.dxf, keys.dxf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]
2024-03-16 infused-kim submodule
    [travis_erg2024.kicad_pcb]
2024-03-16 points fix
    [combo.dxf, keyholes.dxf, keys.dxf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]
2024-03-16 revert holes
    [travis_erg2024.kicad_pcb]
2024-03-16 cap adjustment
    [travis_erg2024.kicad_pcb]
2024-03-17 new text, fixed version, scotto's diodes
    [travis_erg2024.kicad_pcb]
2024-03-18 slight adjust
    [board.dxf, board3d.dxf, bottom.stl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]
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2024-03-19 add rotation to custom footprints
    [travis_erg2024.kicad_pcb]
2024-03-19 footprint net updates
    [travis_erg2024.kicad_pcb]
2024-03-19 fix net references
    [travis_erg2024.kicad_pcb]
2024-03-20 working on separate key
    [board.dxf, combo.dxf, keys.dxf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]
2024-03-21 key module
    [board.dxf, combo.dxf, keys.dxf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]
2024-03-21 notes, rtl module with connections
    [travis_key-rtl.kicad_pcb]
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2024-03-22 key module functions with traces
    [board.dxf, combo.dxf, keys.dxf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]
2024-03-22 key progress
    [board.dxf, combo.dxf, keys.dxf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]
2024-03-23 footprint wip
    [travis_erg2024.kicad_pcb, travis_key-ltr.kicad_pcb, travis_key.kicad_pcb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]
2024-03-23 rtl option added
    [board.dxf, combo.dxf, keys.dxf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]
2024-03-23 minor label tweak
    [travis_erg2024.kicad_pcb, travis_keytest.kicad_pcb]
2024-03-24 stab adjust
    [travis_erg2024.kicad_pcb]
2024-03-24 splay adjust
    [board.dxf, board3d.dxf, bottom.stl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]
2024-03-24 adjusting splay
    [board.dxf, board3d.dxf, bottom.stl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]
2024-03-24 footprint updates
    [travis_erg2024.kicad_pcb, travis_key.kicad_pcb, travis_keytest.kicad_pcb]
2024-03-24 pcb render
    [board.dxf, board3d.dxf, bottom.stl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]
2024-03-24 minor label fix
    [travis_erg2024-new3.kicad_pcb, travis_erg2024.kicad_pcb, travis_keytest.kicad_pcb]
2024-03-25 updating routes
    [travis_erg2024-new3.kicad_pcb, travis_erg2024.kicad_pcb]
2024-03-25 footprint/module updates
    [ergogen.kicad_pcb, ledSK6812minie.kicad_pcb, mountinghole.kicad_pcb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]
2024-03-26 routing v4
    [travis_erg2024-new4.kicad_pcb, travis_erg2024.kicad_pcb, travis_keytest.kicad_pcb]
2024-03-27 wired, gerber file generation
    [travis_erg2024-new2.kicad_pcb, travis_erg2024-new3.kicad_pcb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]
2024-03-29 attempt to fix qmk
    [keymap.c]
2024-03-31 new mcu footprint, mux fixes
    [travis_erg2024.kicad_pcb]
2024-03-31 [200~evqwgd001~ footprint added
    [evqwgd001.kicad_pcb, travis_erg2024.kicad_pcb]
2024-03-31 added ec11
    [ec11.kicad_pcb, travis_erg2024.kicad_pcb]
2024-04-01 wired v5
    [bom.csv, designators.csv, positions.csv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]
2024-04-01 minor value updates
    [bom.csv, travis_erg2024.kicad_pcb]
2024-04-05 led matrix
    [travis_erg2024-all-pos-LEDs.ods, travis_erg2024-all-pos.csv]
2024-04-05 mux still off by 1
    [travis_erg2024-all-pos-LEDs.ods]
2024-04-06 v6 of routing
    [bom.csv, positions.csv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]
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2024-04-16 leds added in the correct order
    [travis_erg2024-new6-all-pos-LEDs.ods]
2024-04-30 add row2col option and use that
    [travis_erg2024-v7.kicad_pcb, travis_erg2024.kicad_pcb]
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2024-05-09 updated footprints, version, added diode to leds
    [travis_erg2024-v8.kicad_pcb, travis_erg2024.kicad_pcb]
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2026-01-19 scotto rp2040 adjust labels to auto flip
    [ScottoKeebs-RP2040_Pro_Micro.js]
